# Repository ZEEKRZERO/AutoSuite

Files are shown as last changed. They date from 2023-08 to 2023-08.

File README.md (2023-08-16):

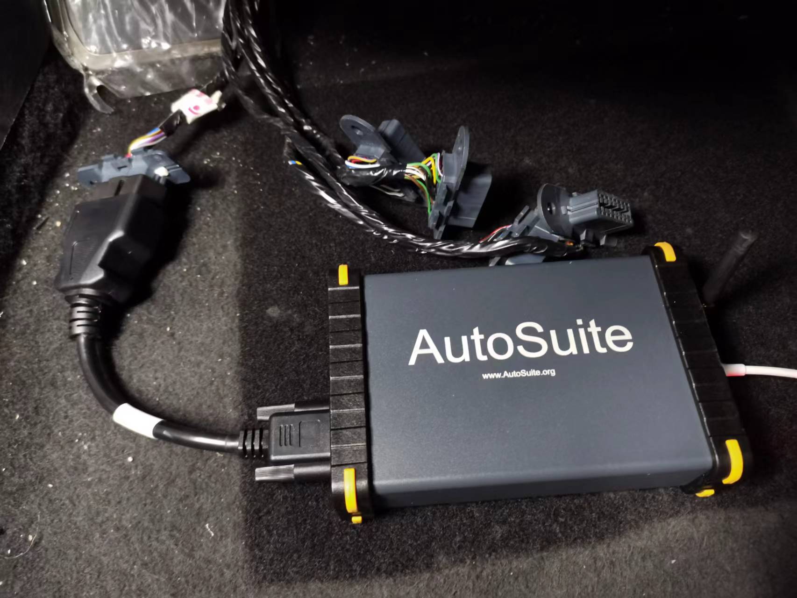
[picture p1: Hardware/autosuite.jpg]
harware

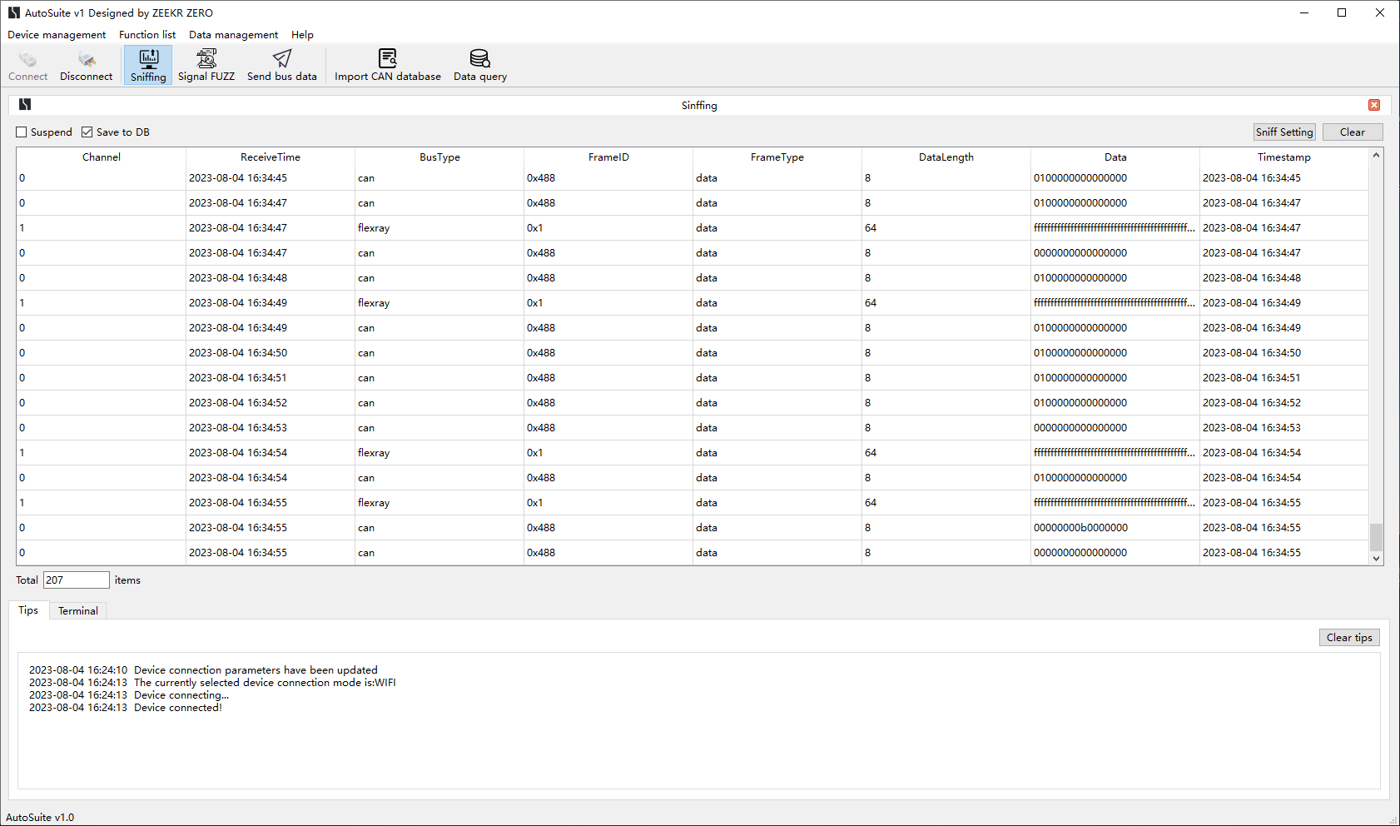
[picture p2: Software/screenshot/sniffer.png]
software1


# AutoSuite
Autosuite:an open source multi-protocol low-cost vehicle bus testing framework 
AutoSUite consisting of the hardware and software. AutoSuite can be used to access the FlexRay bus and simulate malicious ECUs to send forged data to realize cross-domain ECU attacks and discover potential security vulnerabilities.  
# Architecture
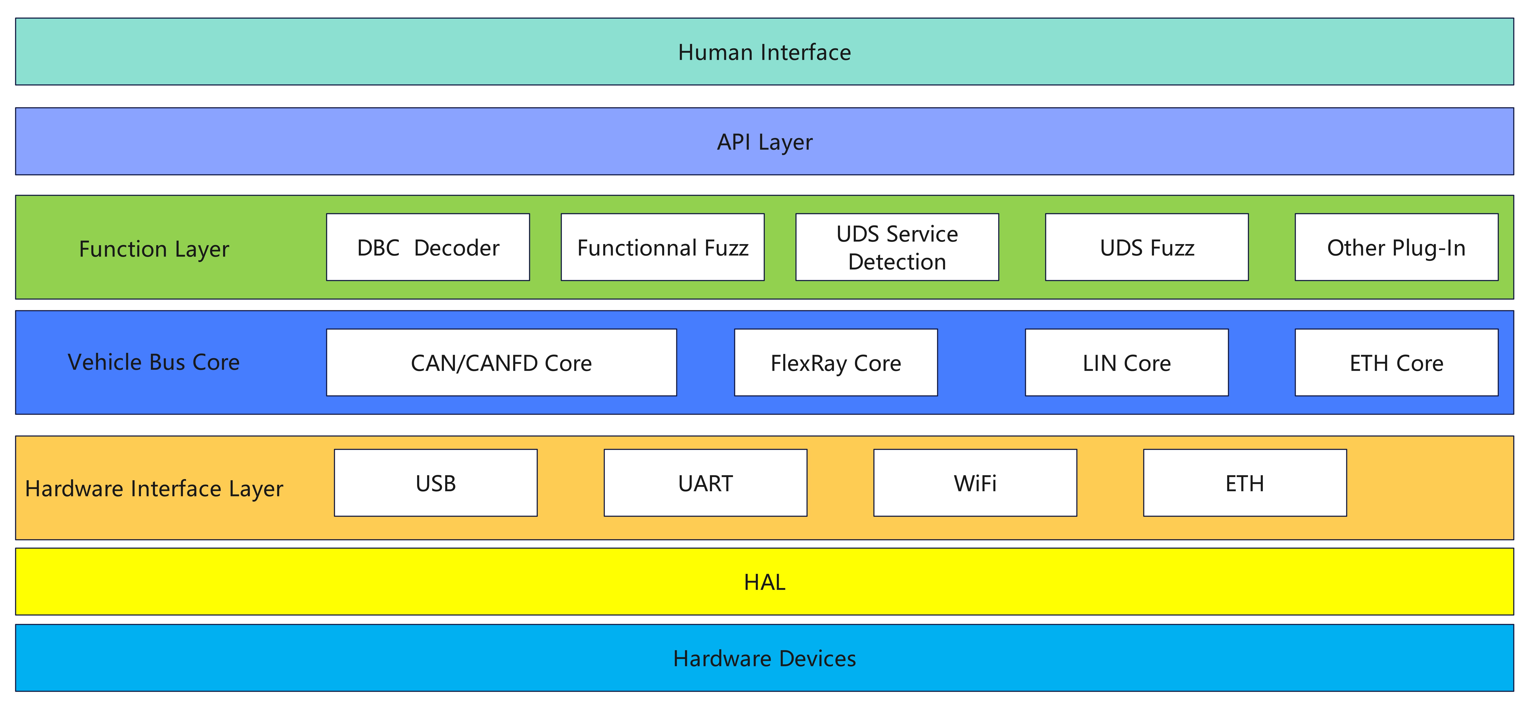
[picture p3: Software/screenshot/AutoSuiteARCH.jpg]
arch

## 3D
The STL/DXF/DWG file of metal shell of AutoSuite, you can 3D print or CNC your own AutoSuite shell.
## Hardware
Schematic and PCB included, you can make pcb with gerber file, component list is in BOM. 
## Firmware 
Including .elf file of MPC5748G and .bin file of ESP32(WiFi module).
## Software
### Requirements
```
pip install PySider6
pip install hidapi
pip install cantools
pip install pyserial
```
### Usage
```
cd AutoSuite/Software
python mainWindow.py
```
#### Connect Device
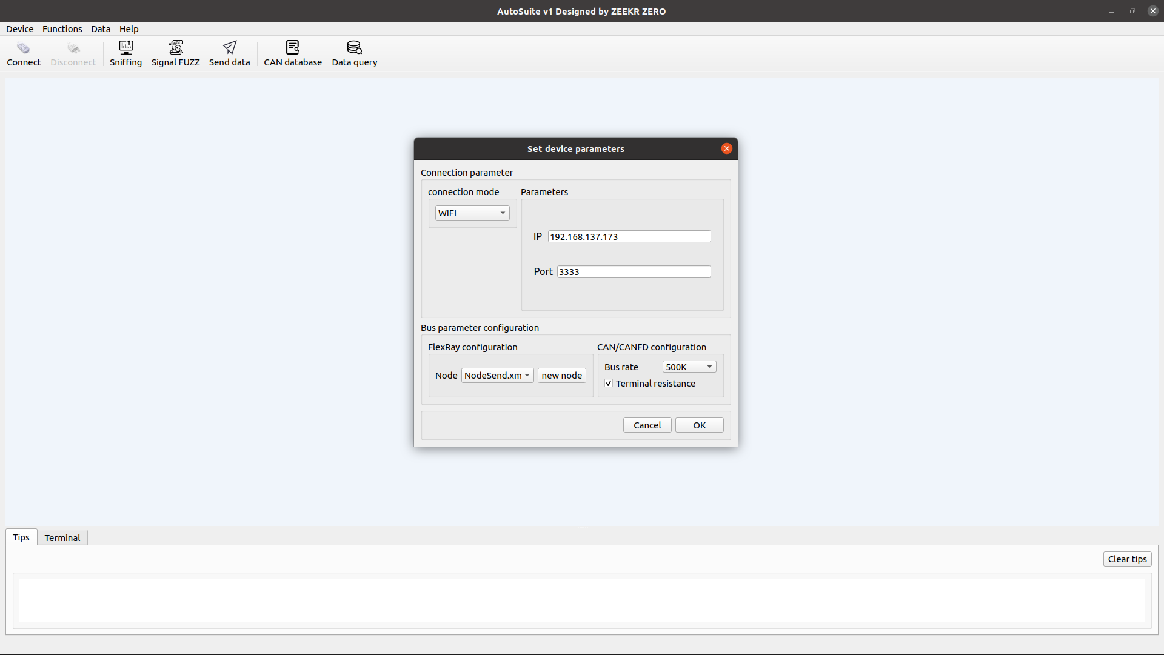
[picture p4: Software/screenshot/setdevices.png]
connect

* Click **Device-->Set Device Parameters**, choose **Connection Mode**, and config bus parameters.
* Click **Connect** to connect device. 

#### Sniffing 
sniff 
#### Signal Fuzz 
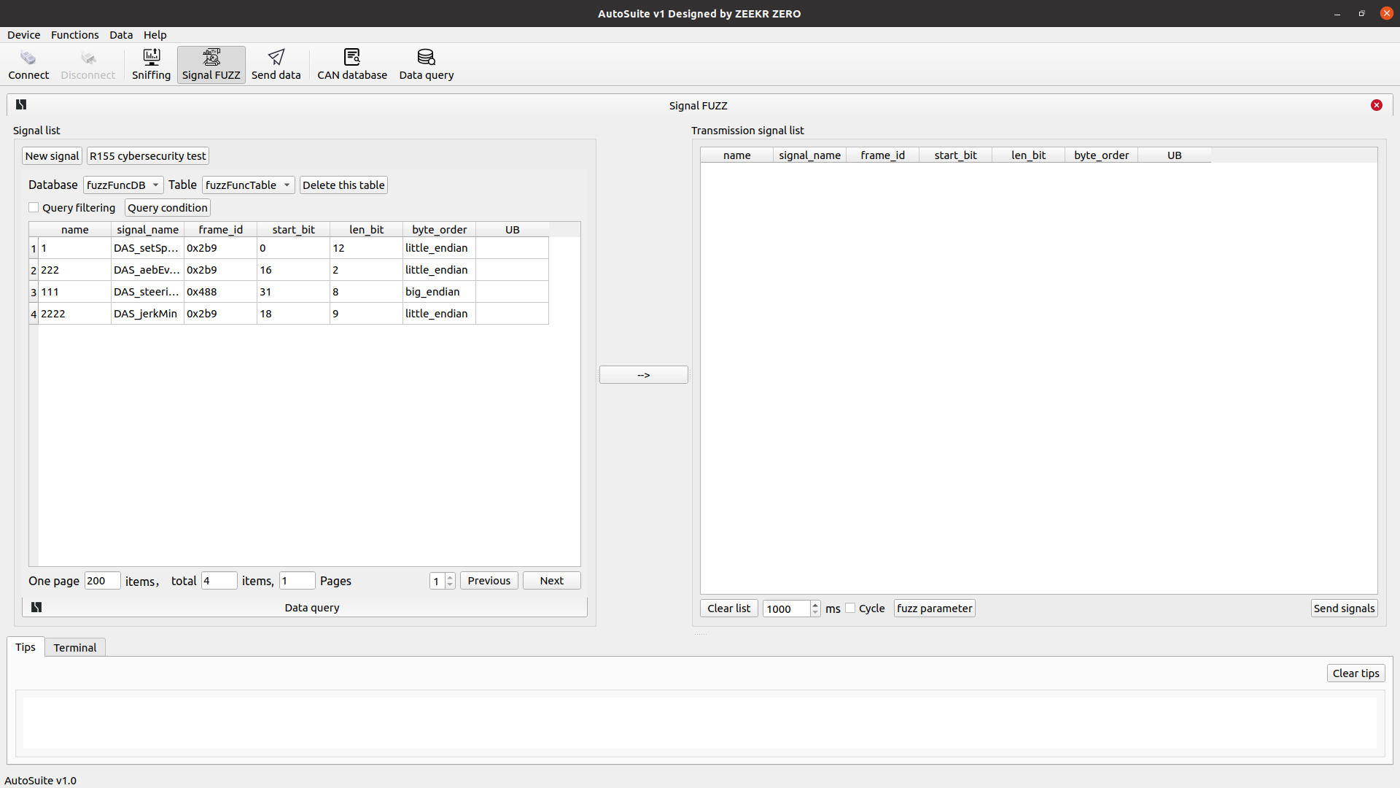
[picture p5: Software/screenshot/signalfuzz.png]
fuzz
 
#### Import and Parse DBC 
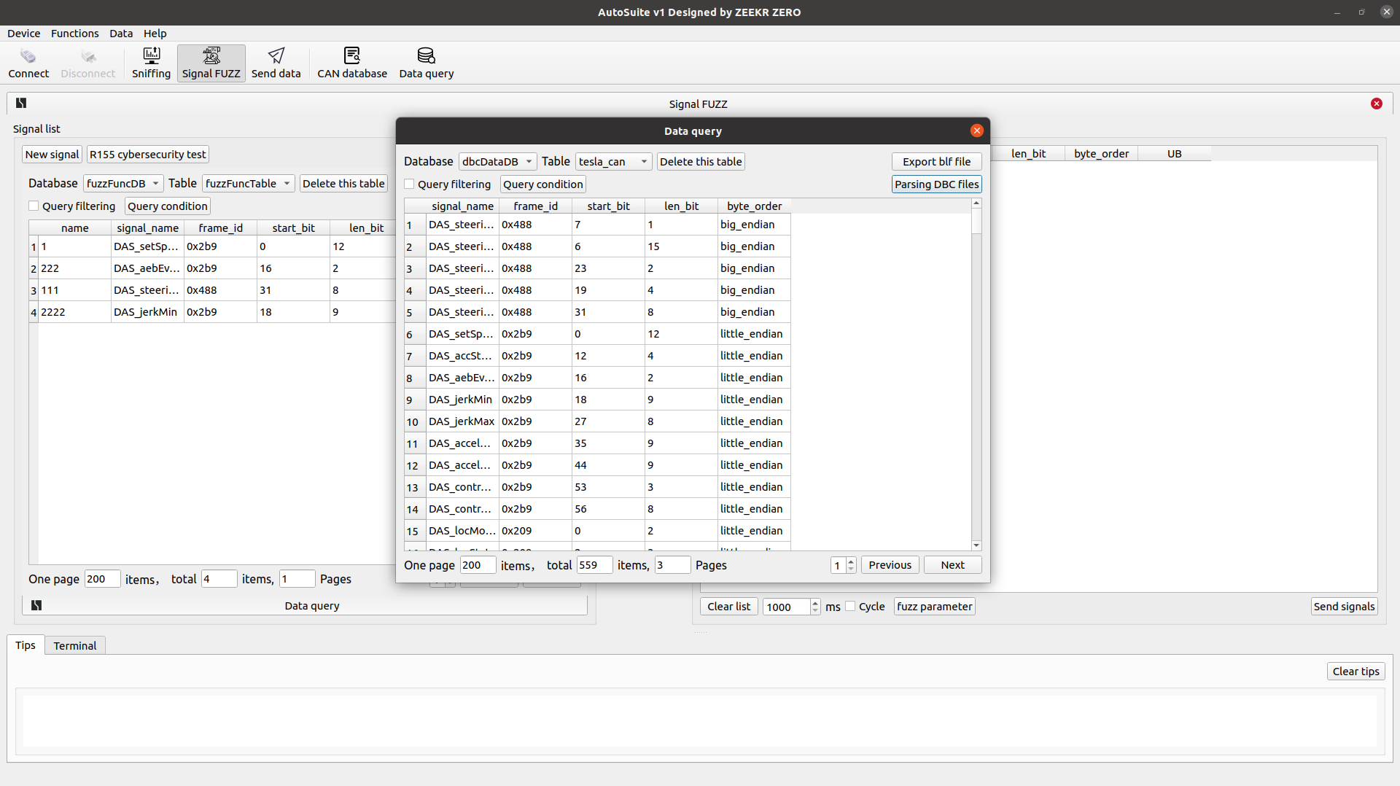
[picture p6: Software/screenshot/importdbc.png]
dbc
  
#### Send Data
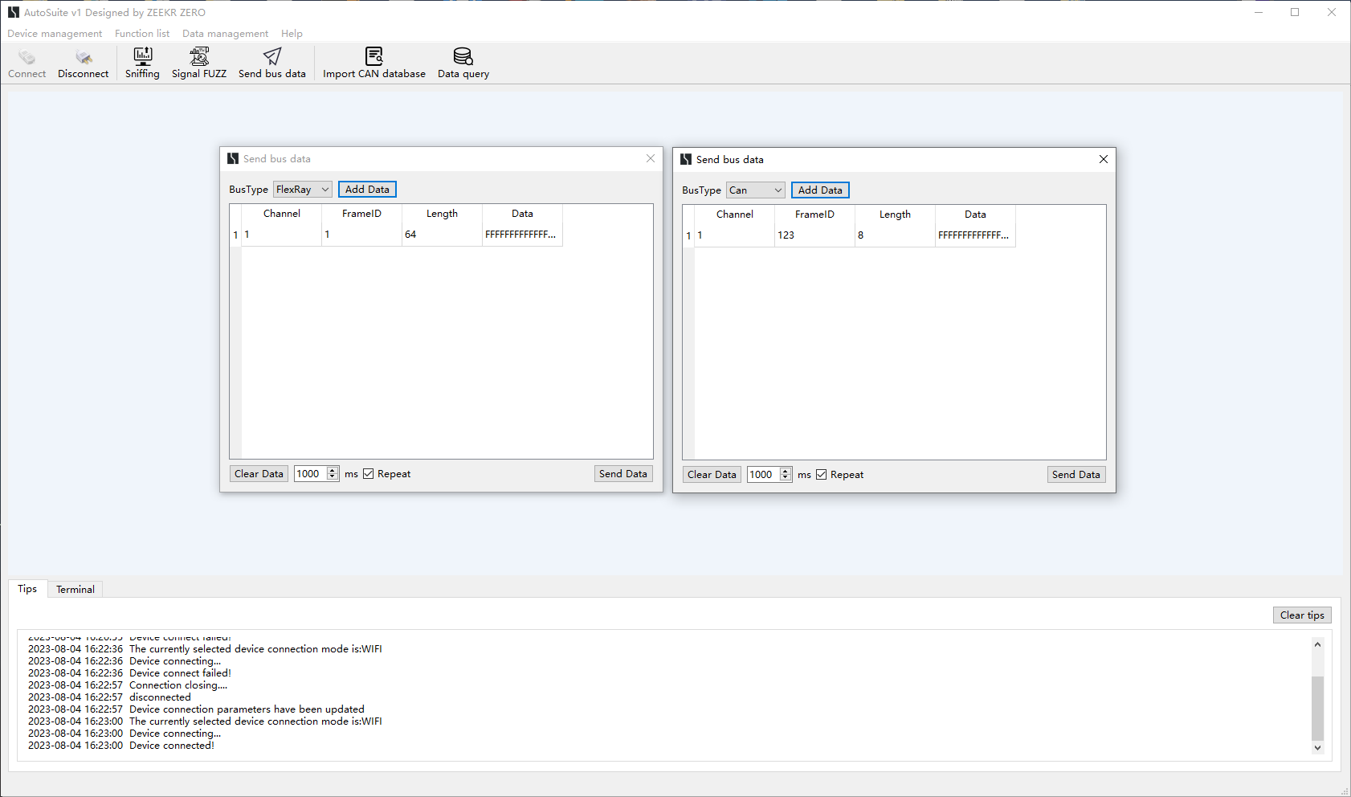
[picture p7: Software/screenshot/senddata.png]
senddata


### Create EXE
Run AutoSuite/Software/pack.bat
## Reference
* [MPC5748G Microcontroller Data Sheet](https://www.nxp.com.cn/docs/en/data-sheet/MPC5748G.pdf) 
* [MPC5748G Hardware Design Guidelines](https://www.nxp.com/webapp/Download?colCode=AN5220) 
* [MPC574xG SDK Hands On Training](https://www.nxp.com/webapp/Download?colCode=MPC574xG-SDK-HOT) 
* [openpilot/flexray_adapter/](https://github.com/nanamiwang/openpilot/tree/flexray_bounty/flexray_adapter) 
* [opendbc](https://github.com/commaai/opendbc) 
* [FlexRay Protocol Specification Version 2.1 Revision A](https://www.softwareresearch.net/fileadmin/src/docs/teaching/SS08/PS_VS/FlexRayCommunicationSystem.pdf)    
## Licensing
MIT License

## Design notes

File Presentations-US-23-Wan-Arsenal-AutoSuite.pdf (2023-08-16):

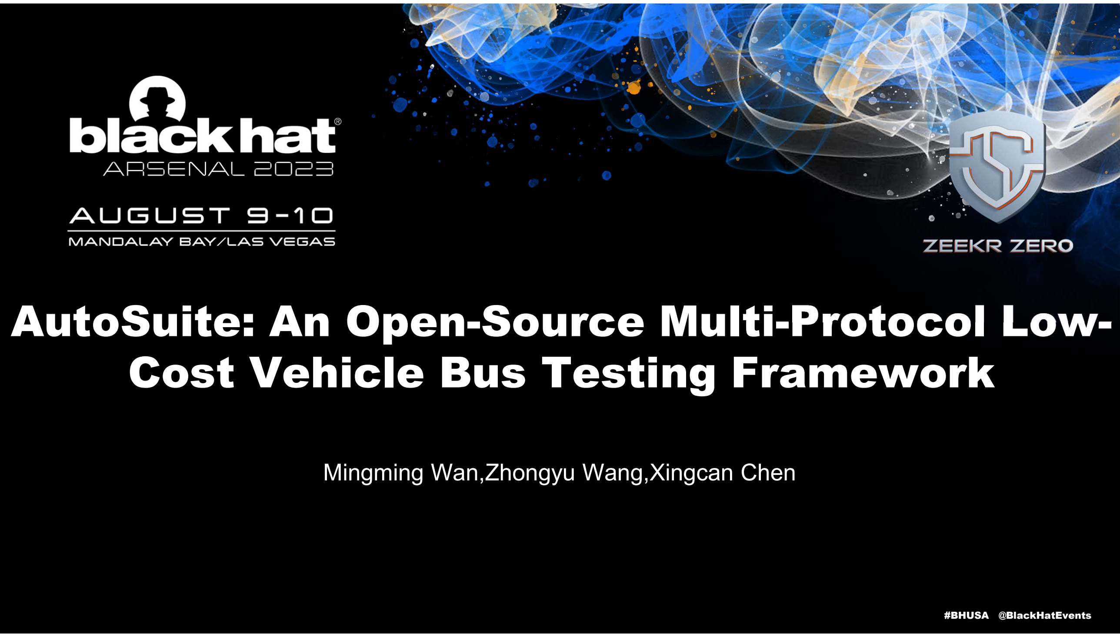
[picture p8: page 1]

## #BHUSA @BlackHatEvents

# AutoSuite: An Open-Source Multi-Protocol Low-Cost Vehicle Bus Testing Framework

# Mingming Wan,Zhongyu Wang,Xingcan Chen

## #BHUSA @BlackHatEvents

Information Classification: General

# Mingming Wan BlackHat USA 2017 Briefings Speaker Senior Hardware Engineer of ZEEKR AUTO

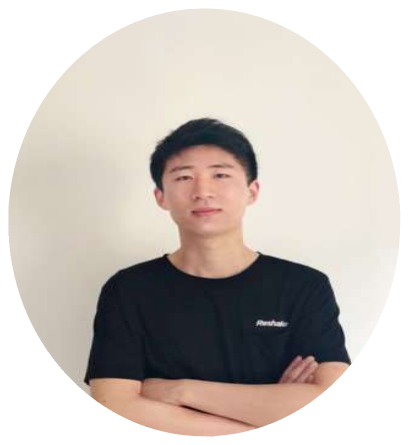
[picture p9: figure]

# wanmingming2008@gmail.com

# Zhongyu Wang IoT Group Head of ZEEKR AUTO wang3919379@gmail.com

# Xingcan Chen Hardware Security Engineer of ZEEKR AUTO icon.xxxc@gmail.com

# About US

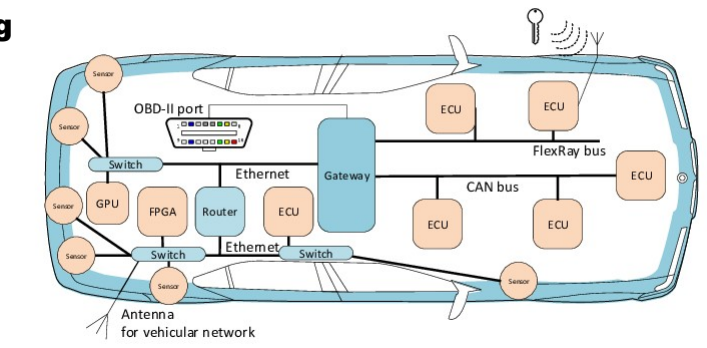
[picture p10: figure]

## #BHUSA @BlackHatEvents

Information Classification: General

# Vehicle Bus

# - Communication among different systems - Data Transfer in the form of signals

- FlexRay, CAN, LIN,

# ETH(DoIP) - Diagnostics for Troubleshooting

# Vehicle Bus Vulnerabilities

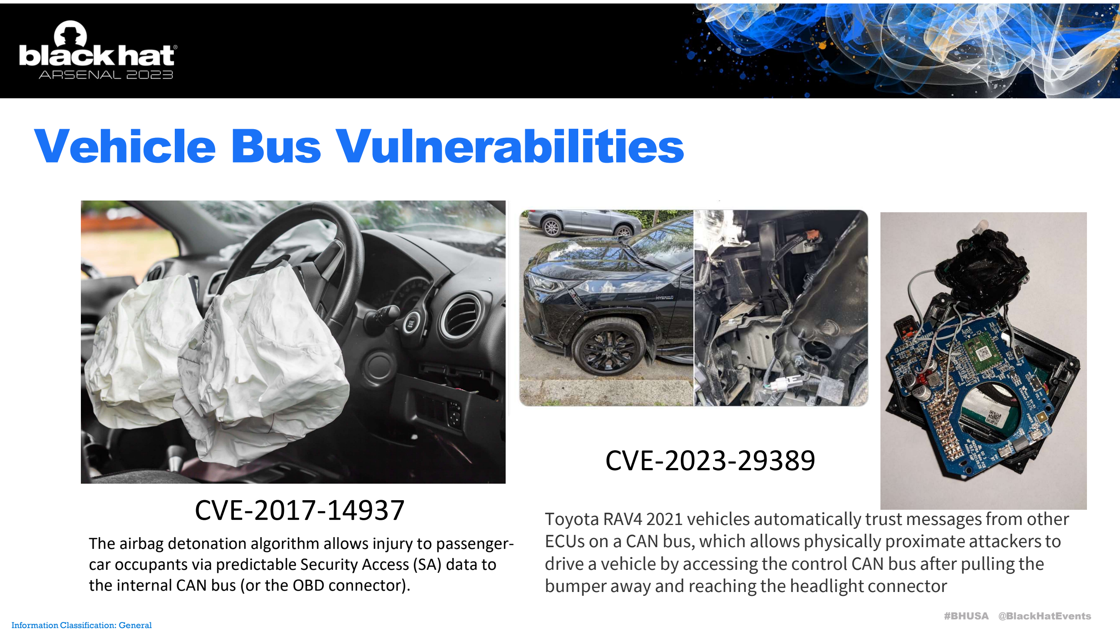
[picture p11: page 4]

## #BHUSA @BlackHatEvents

Information Classification: General

# CVE-2017-14937

# CVE-2023-29389

# The airbag detonation algorithm allows injury to passenger-car occupants via predictable Security Access (SA) data to

the internal CAN bus (or the OBD connector).

# Toyota RAV4 2021 vehicles automatically trust messages from other ECUs on a CAN bus, which allows physically proximate attackers to drive a vehicle by accessing the control CAN bus after pulling the bumper away and reaching the headlight connector

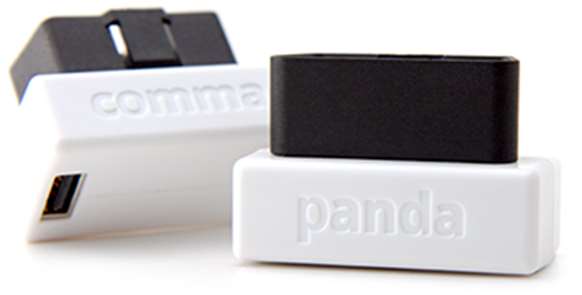
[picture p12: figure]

## #BHUSA @BlackHatEvents

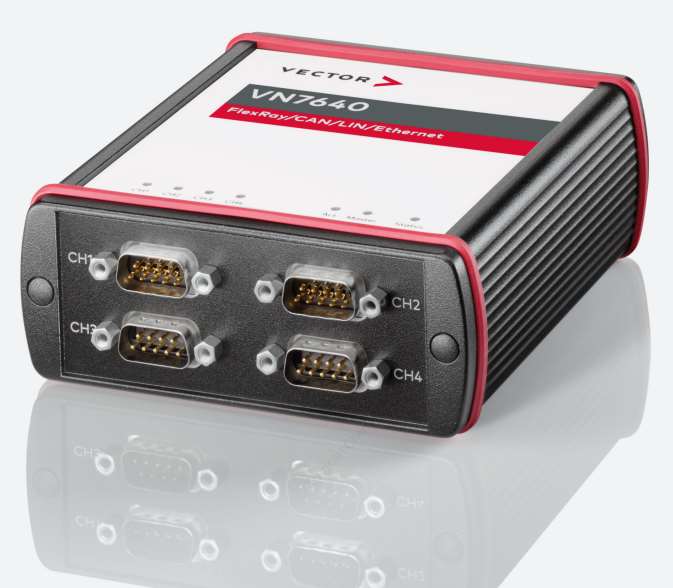
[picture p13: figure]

Information Classification: General

# Vehicle bus Tools

Vector VN7640 | CANable,CANdelight, | Panda
$50K | Open Source CAN ONLY

# FlexRay, CAN, LIN CAN,LIN

# OBD Port

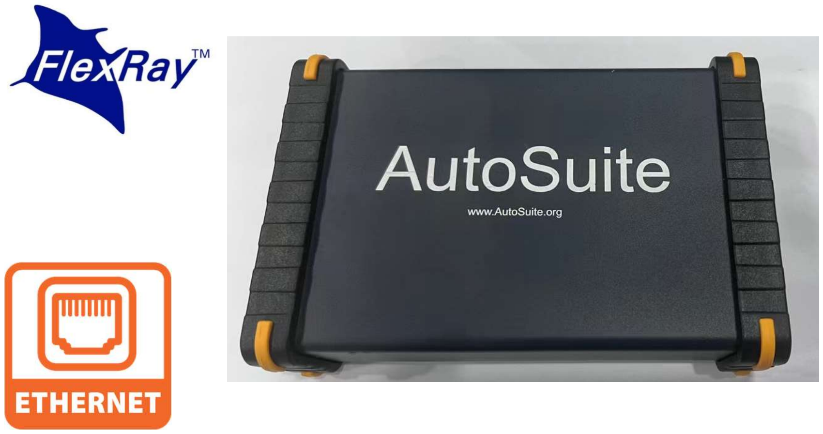
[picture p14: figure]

## #BHUSA @BlackHatEvents

Information Classification: General

# - Open-source

# - Multi-protocol supported

# - Low-cost

# - Functional Fuzz

# What is AutoSuite ?

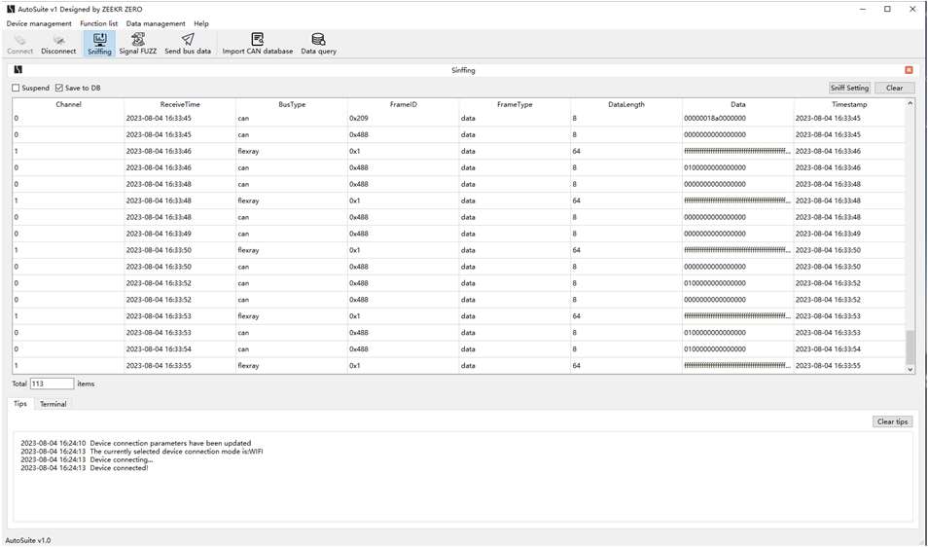
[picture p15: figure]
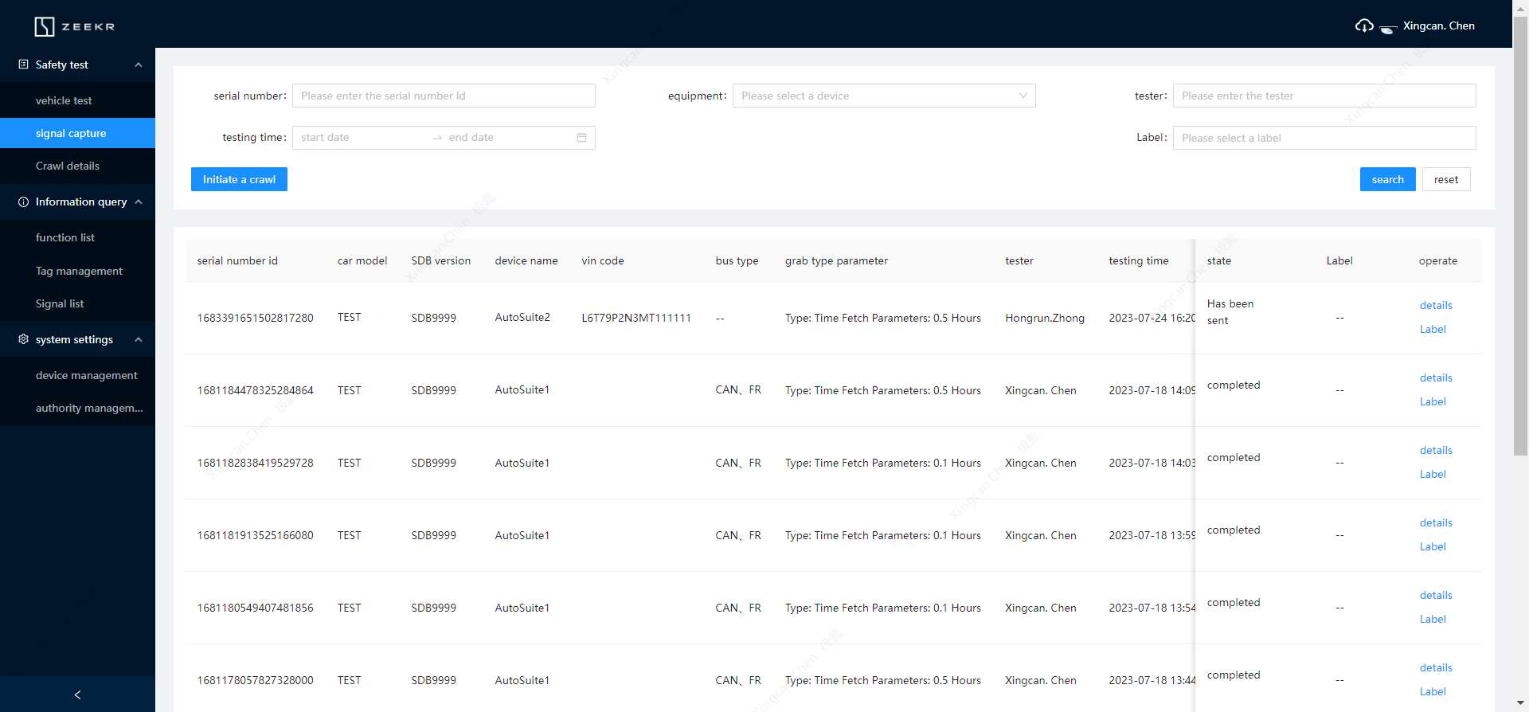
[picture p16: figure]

## #BHUSA @BlackHatEvents

Information Classification: General

# AutoSuite Features

# Plug-in Supported : Developed with PySider6

Cross-Platform: Windows, Linux,

# MAC

# Flexible application : Client and Website

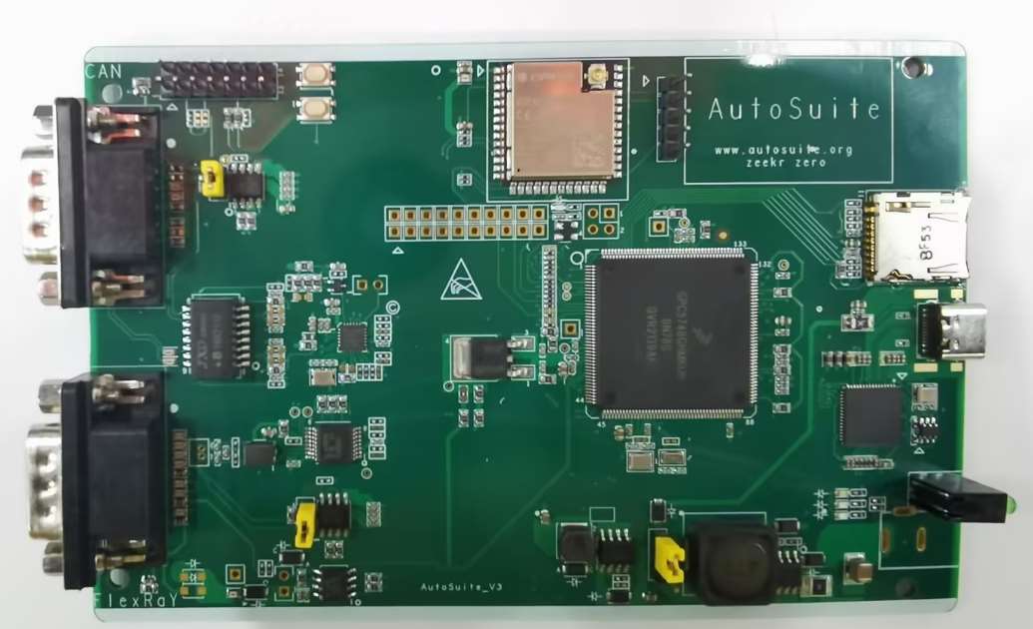
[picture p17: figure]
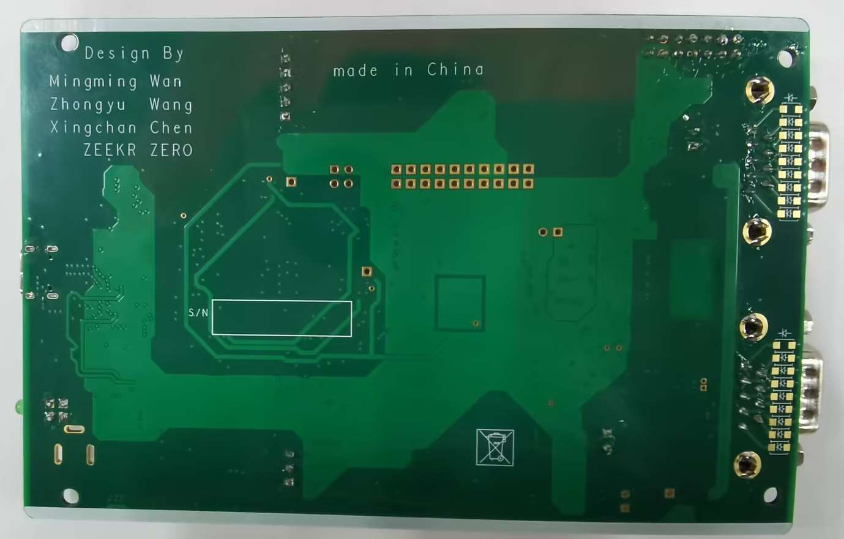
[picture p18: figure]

## #BHUSA @BlackHatEvents

Information Classification: General

# AutoSuiteFeatures

# 6-Layer PCB Both USB Type-C 5V and OBD power 12V options available WiFi Connect

# Coming soon：

# 5G module SD card storage 100BASE-T1

FlexRay CAN/CANFD LIN | ETH
Support √ √ √ | √
Current Channels 1 2 1 | 1
Max Channels 2 8 16 | 2

# AutoSuite

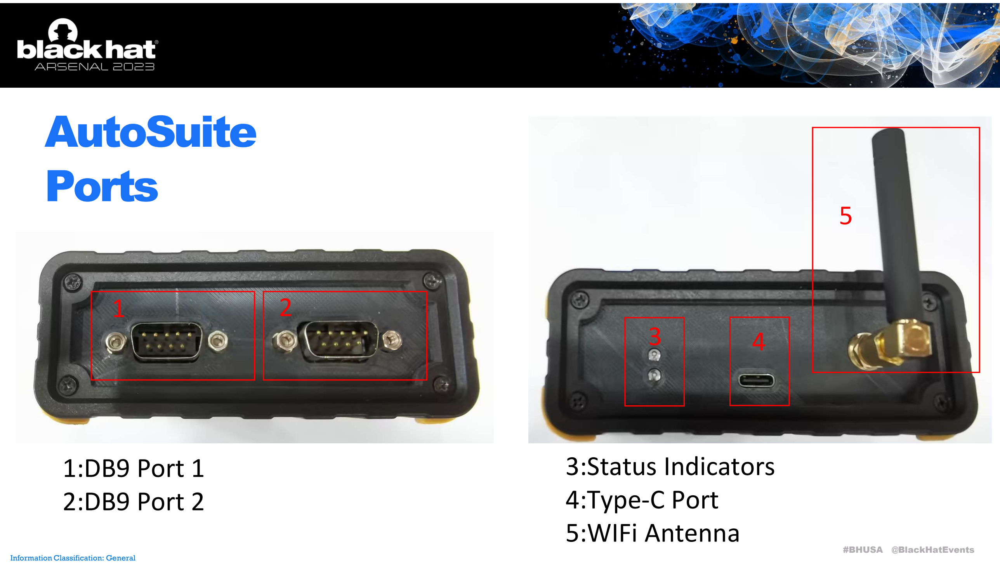
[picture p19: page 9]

## #BHUSA @BlackHatEvents

Information Classification: General

# Ports

1 2
3 4

5

# 1:DB9 Port 1 2:DB9 Port 2

# 3:Status Indicators 4:Type-C Port 5:WIFi Antenna

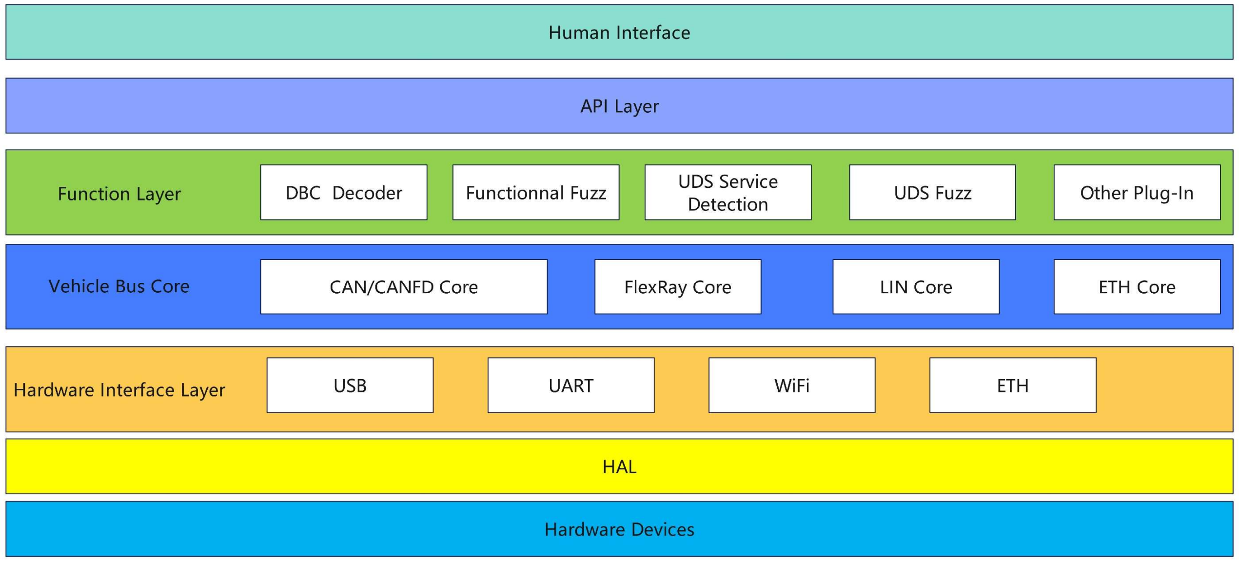
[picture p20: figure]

## #BHUSA @BlackHatEvents

Information Classification: General

# AutoSuite Architecture

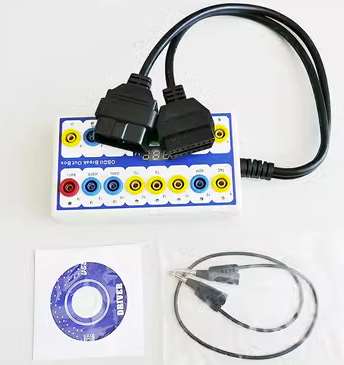
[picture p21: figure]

## #BHUSA @BlackHatEvents

Information Classification: General

# - There are lots of OBD ports for testing reserved

in vehicle R&D stage.

# - R&D engineer, functional safety testers and cyber security testers can directly and use

AutoBox for testing.

- Including FlexRay, CAN/CANFD, LIN and ETH.

# - If OBD port for testing is not reserved, broken

cable tool is helpful.

# How AutoSuite Work

# OBD(On-board diagnostics)

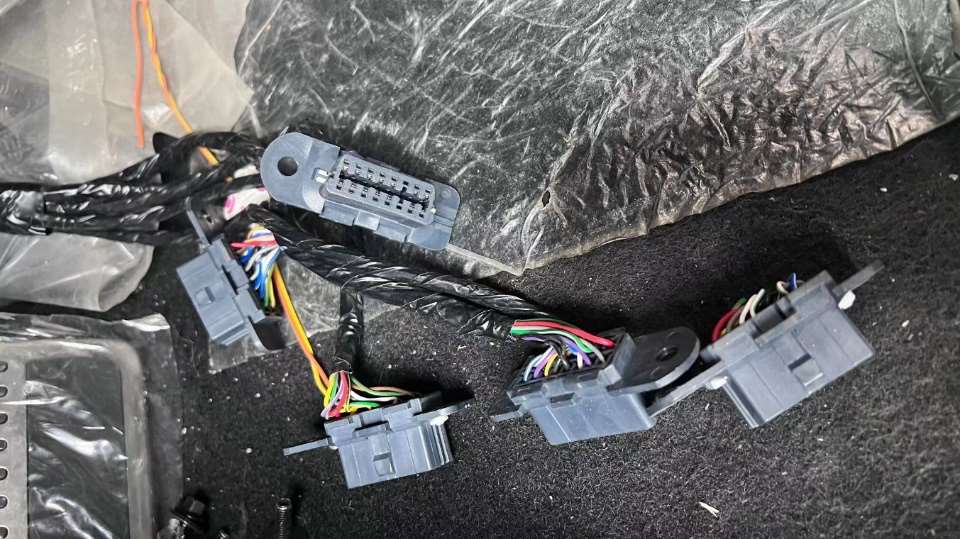
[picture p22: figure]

# OBD in Vehicle OBD converter

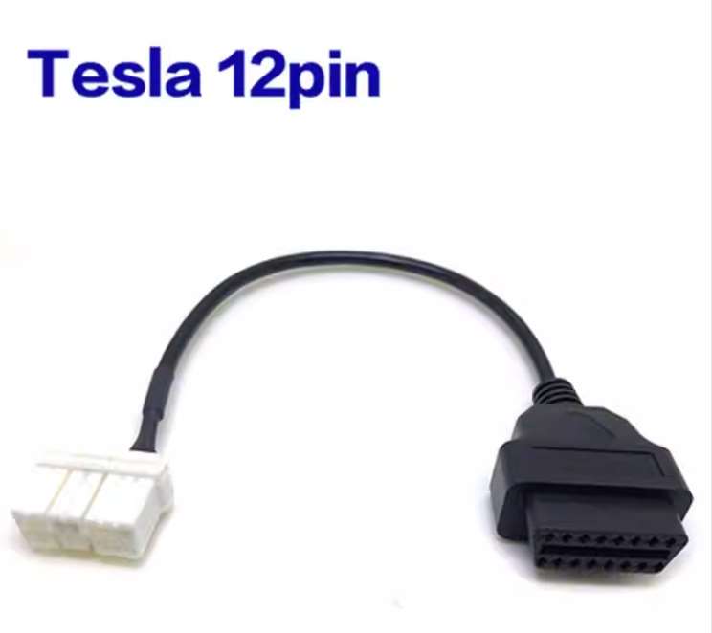
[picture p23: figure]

# OBD converter

# Broken cable tool

# AutoSuite Sniff

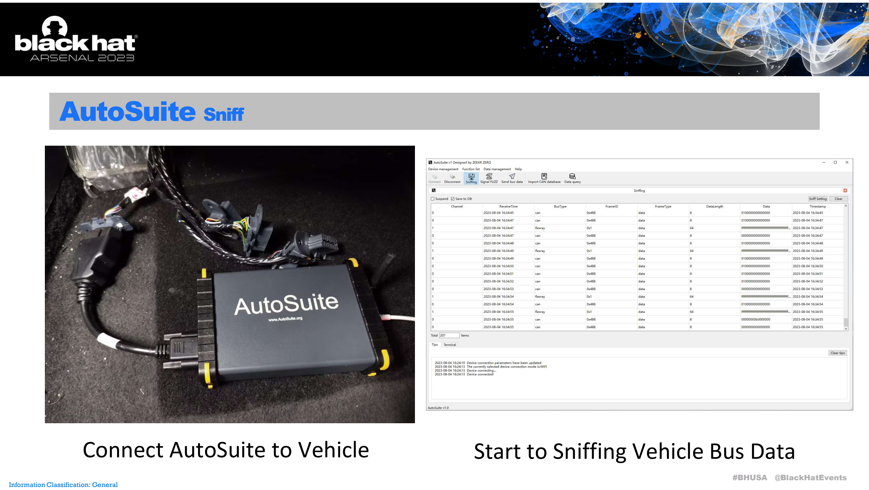
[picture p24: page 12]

## #BHUSA @BlackHatEvents

Information Classification: General

Connect AutoSuite to Vehicle | Start to Sniffing Vehicle Bus Data

## #BHUSA @BlackHatEvents

Information Classification: General

# Demo1 Vehicle Bus Sniffing

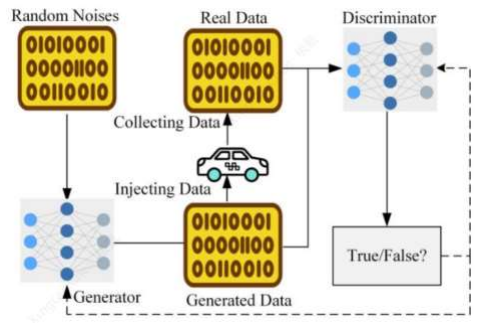
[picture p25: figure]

## #BHUSA @BlackHatEvents

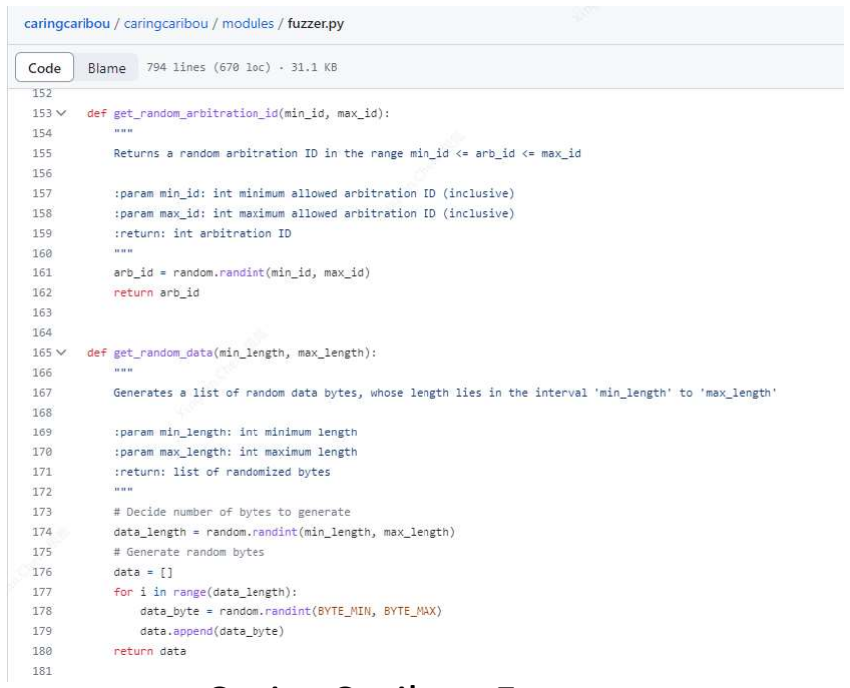
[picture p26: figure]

Information Classification: General

# AutoSuite Functional Fuzz

# CaringCaribou Fuzzer

# CAN-FT - Current Vehicle Fuzzing tools only focus on random generate frame ID or data frame

# - Hard to location root cause

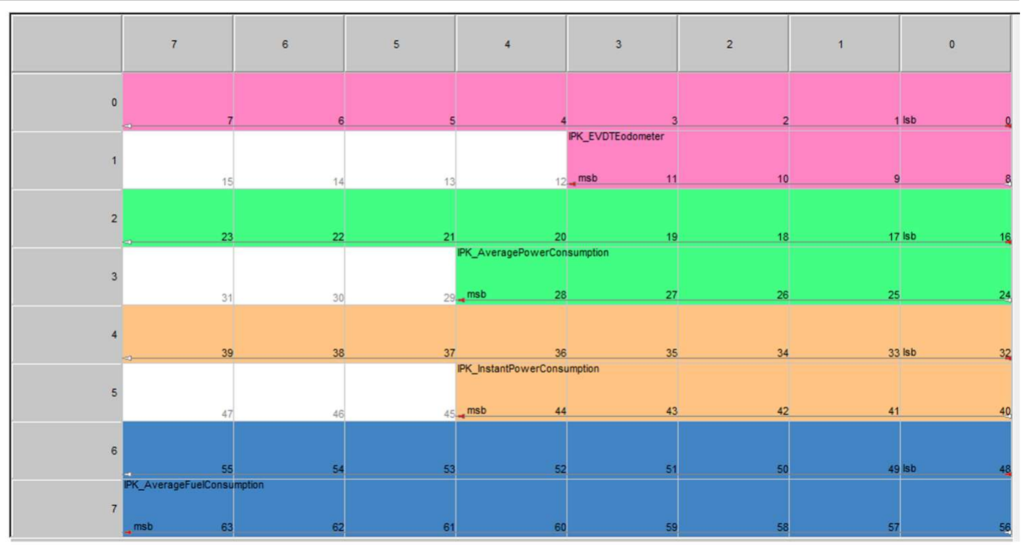
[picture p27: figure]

## #BHUSA @BlackHatEvents

Information Classification: General

# - Functional-level Fuzzing

# - DBC Decode

# - DTC Detection

# - UDS Fuzz

# Signal Layout in CAN Frame

# AutoSuite Functional Fuzz

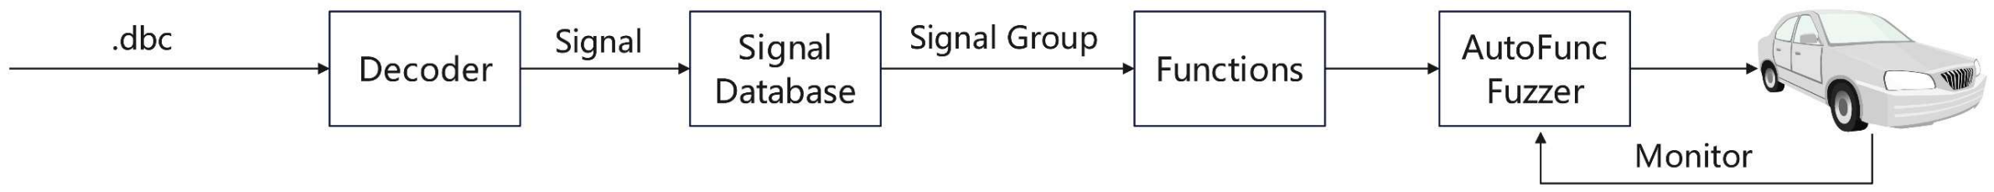
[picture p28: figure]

## #BHUSA @BlackHatEvents

Information Classification: General

# Workflow of Functional Fuzzer

# AutoSuite Functional Fuzz

# AutoSuite R155 Cybersecurity Test

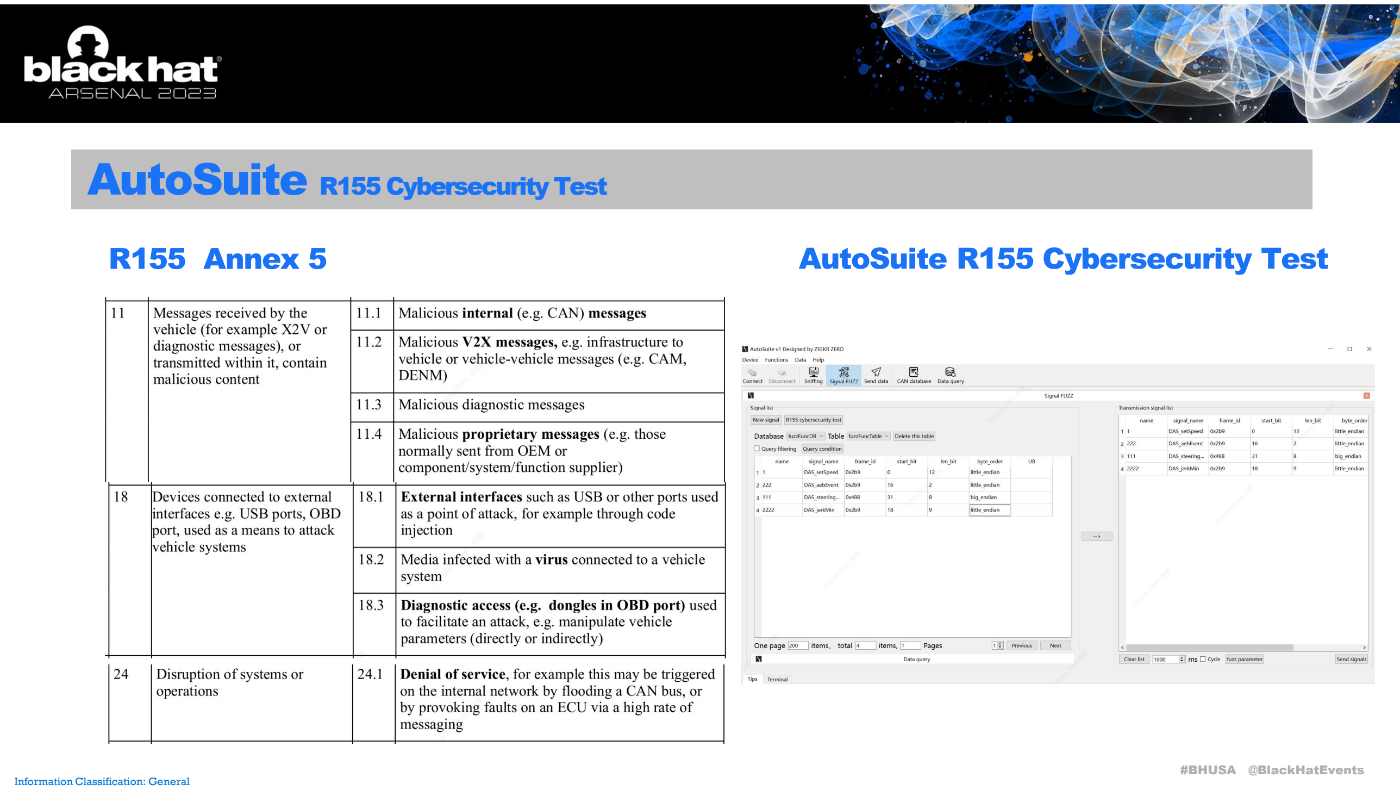
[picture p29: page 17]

## #BHUSA @BlackHatEvents

Information Classification: General

R155 Annex 5 | AutoSuite R155 Cybersecurity Test

## #BHUSA @BlackHatEvents

Information Classification: General

# Demo2 Functional Fuzz

## #BHUSA @BlackHatEvents

Information Classification: General

# Autosuite Application Scenarios

# - For WP.R155 Testing

# - For Chinese Vehicle security Law Testing

# - For Vehicle Charge Pile Testing

# Auto Cyber Security Testing

# - Personal vehicle security researcher

# Easy to use

# Low-Cost

# Personal Security Research

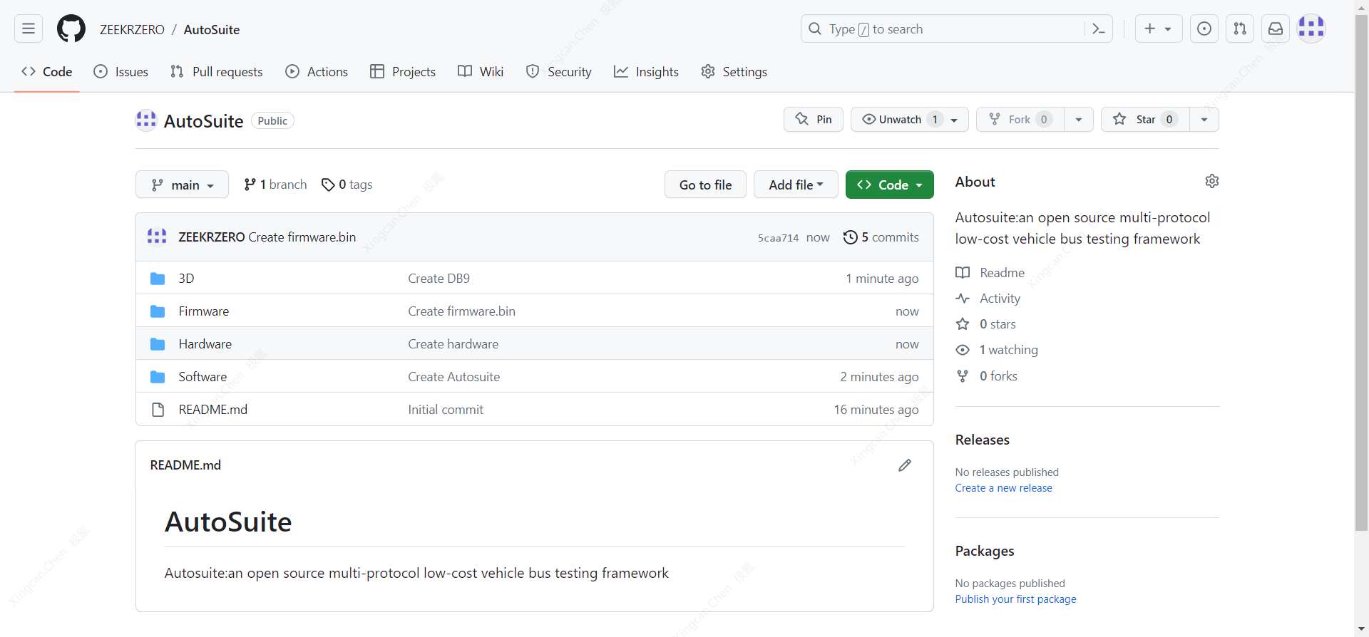
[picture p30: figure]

## #BHUSA @BlackHatEvents

Information Classification: General

# AutoSuite Opensource

# - GitHub.or www.Autosuite.org

# - AutoSuite software has uploaded

# - All PCB components can be purchased on Alibaba or DigiKey. You can make AutoSuite by

yourself in $200.

## #BHUSA @BlackHatEvents

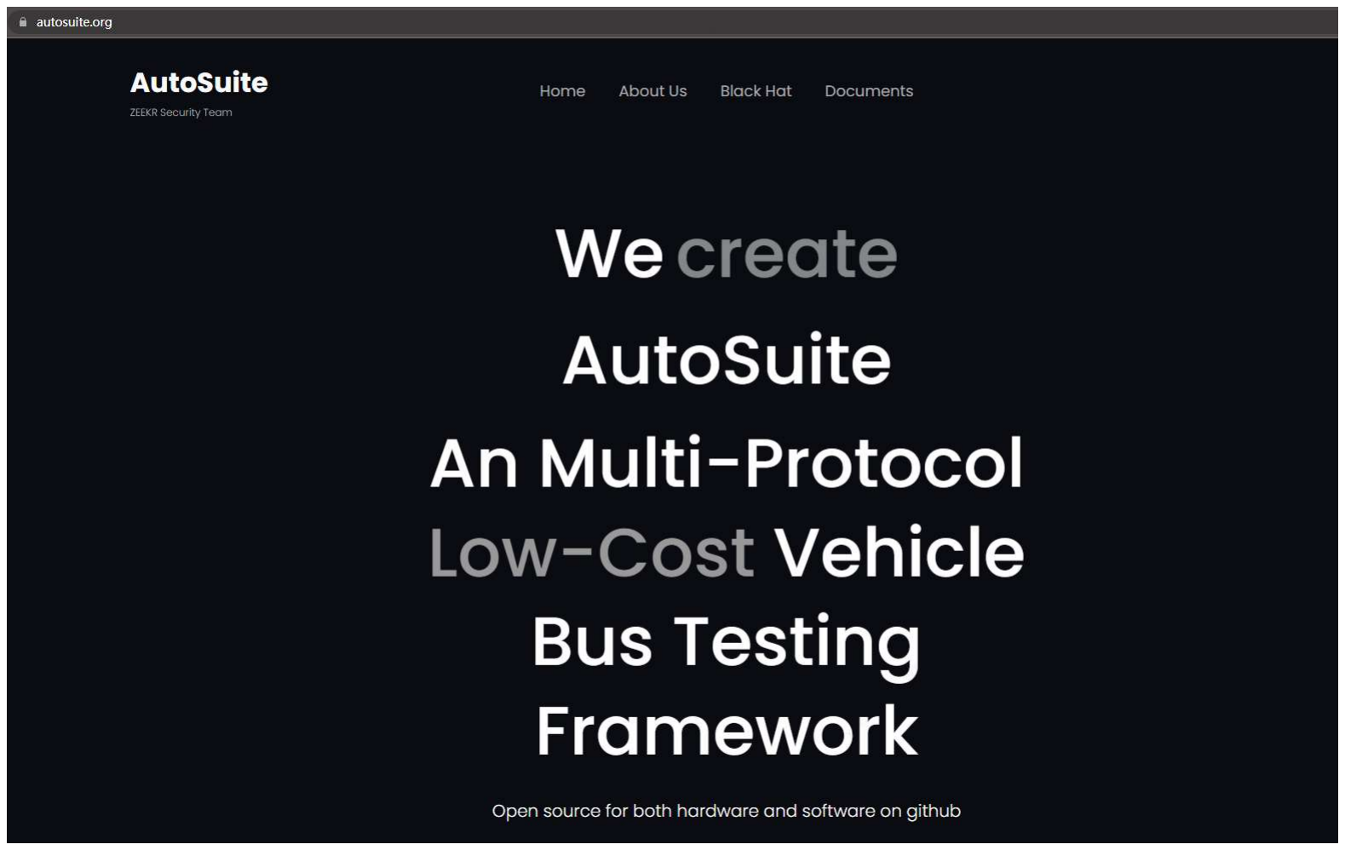
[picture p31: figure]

Information Classification: General

# TO DO

# - High-risk vulnerabilities, integrated POC (Proof of

Concept), modularization.

# - Additional hardware support for in-vehicle bus systems such as automotive Ethernet 100M/10M

and CANXL protocol.

# Please Access www.autosuite.org To Get Latest Information

## #BHUSA @BlackHatEvents

Information Classification: General

# Acknowledgments

# @Safe4 @Fengli Jiang @Alex Wang @Lakka @Jiantao Yan @Cawan

POC2022: Chen Nan & Chongyang Bao & Jiaming Tao, "Explore 'BUS' Mysteries via Automotive fuzzing'

## #BHUSA @BlackHatEvents

Information Classification: General

# Thank you

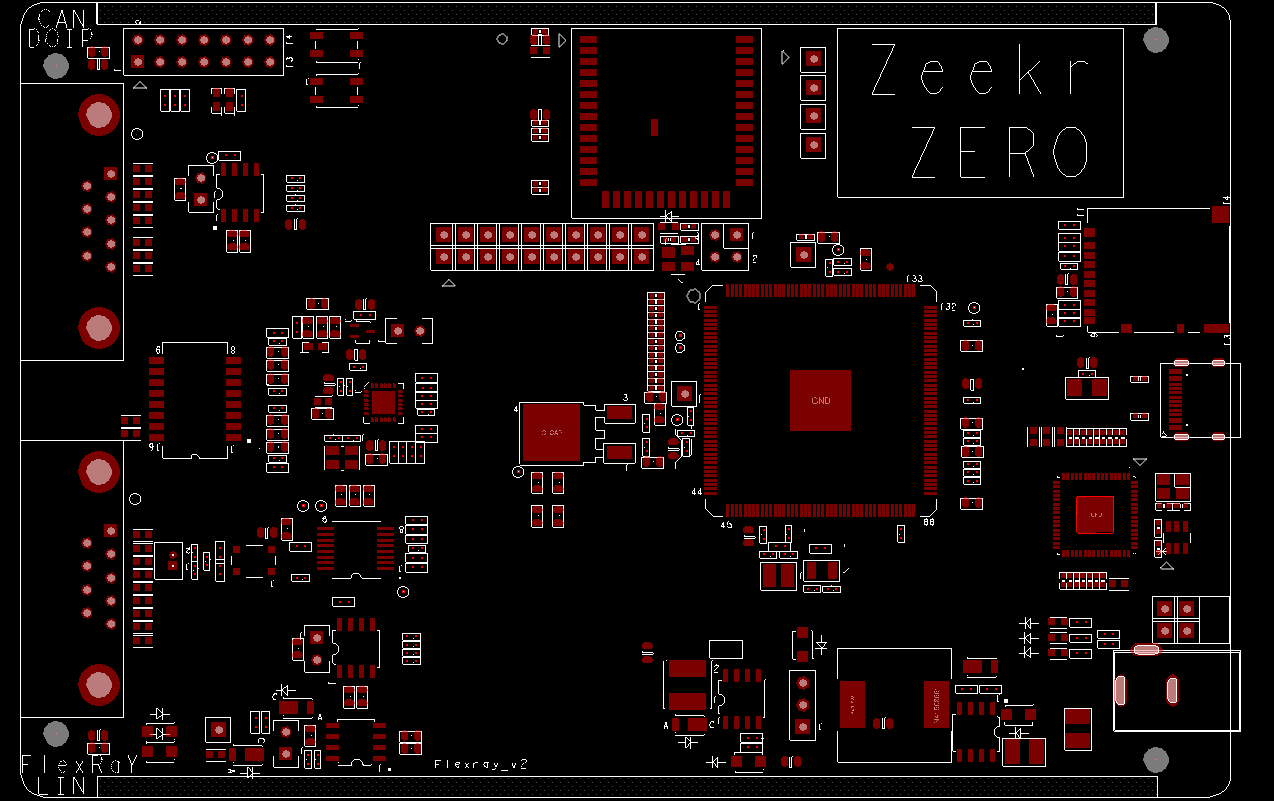
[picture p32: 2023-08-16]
Hardware/PCB/AutoSuite-TOP.png

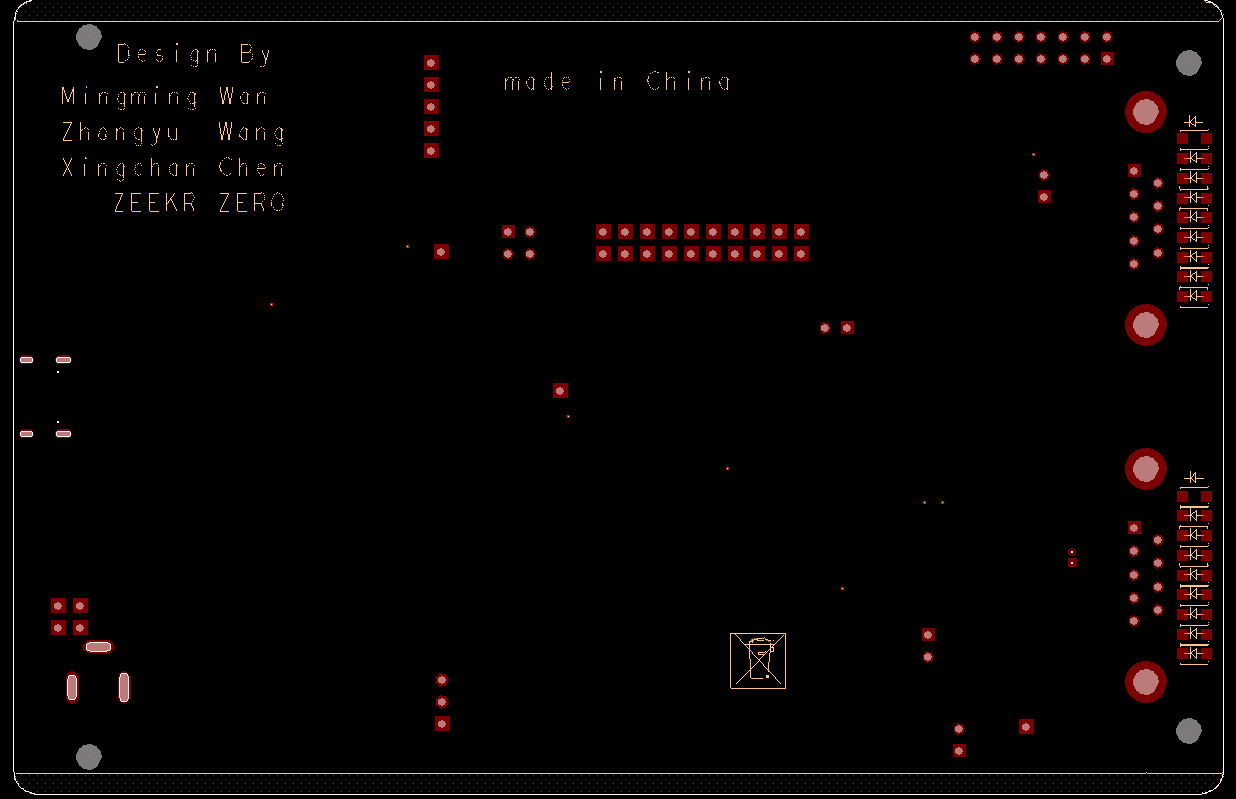
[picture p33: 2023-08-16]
Hardware/PCB/AutoSuite-Bottom.png

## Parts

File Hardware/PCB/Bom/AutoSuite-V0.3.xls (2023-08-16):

型号 | 封装 | 位号 | 元件编号
32.768KHZ | XTAL2-3P2X1P5-SM | Y4 | C130253
USB_TypeC_Receptacle_Mid-Mount | ylc_typec | J28 | C2982555
DLW43SH | IND_DLW43 | L3 | C123085
BAT54AWT1G | sot323_3p | D3 | C894269
4700pF | 0402 | C9,C60 | C1538
22uF | CC1210 | C71 | C52306
FT2232HQ | QFN64 | U499 | C193662
RB1-125BAG1A/TS21C_HF | xfmr16p_050_282x514 | J10 | C510548
TJA1044GT/3 | SO8_1P27_4X5 | U20,U21 | C961486
AP1509-SG-13 | SO8_1P27_4X5 | U18 | C151822
1.0UF | 0603 | C59 | C15849
22 | RC0603_OV | R151 | C23345
93LC56BT-I/OT | SOT-23-6_MC | U44 | C190271
SBR3U30P1 | powerdi-123_3mmx2mm | D1,D2,D5,D6 | C110517
12PF | 0402 | C79,C80,C81,C82 | C1547
40MHZ | xtal2_3p3x2p6 | Y5 | C255943
AP1509-33SG-13 | SO8_1P27_4X5 | U19 | C151823
2.2uF | 0402 | C26 | C12530
2.2uF | 0402 | C5,C48,C54,C69,C73,C1323,C1324,C1 | C12530
22uF | 0603 | C63,C66,C84 | C59461
2K2 | 0402 | R3424 | C25879
47 | 0402 | R23,R30 | C25118
47uH | ind2_12p8x12p8 | L8 | C2981394
4.7uF | 0402 | C222,C1000,C1200,C1777 | C23733
2.0K | 0402 | R1,R2 | C4109
600R/0.5A | 0603 | L53,L222,L333 | C1035
4.7uH | ind_5p2x5p2 | L7 | C135288
4.7UF | C0603 | C333 | C19666
4.7UF | 0603 | C52 | C19666
0R | 0402 | R1390,R1391,R1401,R1402,R1403,R1404,R129735,R129739,R129746,R129747,R138 | C17168
0R/NC | 0402 | R129727,R129728,R129729,R129730 | C17168
24PF | 0402 | C36,C39 | C285039
1.0UF | 0402 | C55,C58,C65,C67 | C52923
10uF | 0603 | C3,C20,C22,C27,C86,C1341,C1342 | C19702
SKRPABE010 | sw4_skrp | SW1,SW3 | C115360
KSZ8081RNACA | qfn24_4x4mm_slug | U17 | C100017
STM6315 | sot_143 | U7 | C2066710
12M | OSC-HCX-3SB | Y111 | C9002
27PF | 0402 | C7024,C8024 | C782161
5.1K | 0402 | R1340,R1341,R1384,R1392,R1394 | C25905
0.68UF | 0603 | C44,C62,C78 | C469639
PMEG4030ER | sod123w | D4,D8,D29 | C389355
0 | CC1210 | R1405 | C474103
0 | RC0603_OV | R3,R4,R15,R17,R42,R49,R58,R59,R60,R61,R62,R63,R67,R89,R91,R97,R98,R103,R111,R112,R113,R117,R124,R125,R126,R141,R142,R156,R1352,R1353,R1354,R1355,R1406,R50,R51 | C21189
6.49K | 0603 | R71 | C2933249
76.8R | 0402 | R165,R166 | C61601
4.7K | 0402 | R119,R1357 | C25900
1.5K | 0402 | R78,R79 | C25867
33 | 0402 | R77,R88,R94,R101,R102 | C25105
10.0K | 0402 | R73 | C25744
10K | 0402 | R19,R29,R35,R40,R54,R1344,R3324 | C25744
10K | 0402 | R28,R34,R36,R46,R47,R53,R87,R147,R148,R152,R153,R154,R155,R157 | C25744
2.2uF | 0603 | C1320,C1322 | C23630
270 | 0402 | R44 | C25099
270 | 0402 | R114,R132,R136 | C25099
10PF | 0402 | C8,C12 | C32949
1.0K | 0402 | R127 | C11702
560 | 0402 | R1349,R1350 | C25172
25MHz±10ppm12pF | SMD3225-4P | Y3 | C9006
520R | 0603 | R1395 | C23193
MJD31CT4G | to252_dpak | Q1 | C57942
0.1UF | 0402 | C4,C6,C10,C13,C14,C15,C28,C31,C40,C43,C45,C46,C50,C51,C56,C57,C61,C64,C68,C70,C74,C75,C76,C77,C85,C1325,C1326 | C1525
0.1UF | 0402 | C21 | C1525
100nF | 0402 | C1343 | C1525
0.1uF | 0402 | C555,C666,C999,C1100,C1555,C7888 | C1525
1000pF | 0402 | C34 | C1523
26OHM | IND_1206A | L4 | C2830251
120OHM | 0603 | L5 | C354394
LED_YELLOW | 0603 | DS2,DS9,DS10 | C965799
4A | 0603 | F5,F6,F7,F8,F9,F10,F11,F12,F13,F14,F15,F18,F19,F22,F23 | C210357
3.09kΩ±0.1% | 0402 | R122 | C852758
RED | 0603 | DS4 | C72041
120 | 0603 | R128,R1356 | C22787
ESP32-S3-WROOM-1U | SMD41_1P27_18 | U3 | C2980296
SPC5748GHK0AMKU6 | LQFP176_0P5_24X24_7P1EP | U16 | C2840606
0R-0603 | 603 | F17,F4,F16,F21,F3,F20 | C883088
1M | 0402 | R130,R133 | NC
1.69K | 0402 | R140 | NC
10K/NC | 0402 | R1345 | NC
0 | 0402 | R21 | NC
49.9 | 0603 | R75,R82,R104,R110 | NC
 | HDR2X2 | P1 | NC
HDR_1X1 | HDR101 | VSUP1,TPH1,VSUP2,TPH2,VSUP3,VSUP4,TPH4,VSUP5,TPH5,VSUP6,TPH6,VSUP7,TPH7,VSUP8,VSUP9,VSUP10,VSUP11,VSUP12,VSUP13,VSUP14,VSUP15,VSUP16,VSUP17,VSUP18,VSUP19,VSUP20,VSUP21,VSUP22,VSUP23,VSUP24,VSUP25 | NC
 | HDR_2X7 | P4 | NC
TJA1081B | SSOP16 | U10 | NC
TPAD_030 | TPAD_030 | TP16,TP17 | NC
DB9-RA | db_ra_plug-10 | J17,J31 | NC
MC33662BLEF | SO8_1P27_4X5 | U1 | NC
CON_1X2 | hdr102_1p25 | P2 | NC
PJ-002A | DC_PWR_JCK_9X14P4X11MMH | J30 | NC
HDR_1X3 | hdr1x3_2p54_th | J11 | NC
SD/MMCSKT | con_sdcard_std_14f_43_sm_ra | J15 | NC
型号 | 封装 | 位号 | NC
SBR3U30P1 | sod123w | D9,D10,D11,D12,D13,D14,D15,D17,D18,D19,D20,D21,D22,D23,D24,D25,D26,D27,D30,D31 | NC
TESTPOINT | tp_th_018 | TPV2,TPV4,TPV7,TPV8,TPV10,TPV12,TPV14,TPV15 | NC
NC | 0603 | R129749 | NC
50 | 0603 | R48 | NC
 | HDR1X2 | J5,J7,J16,J32 | NC
100PF | 0603 | 100PF,±5%,50V | NC

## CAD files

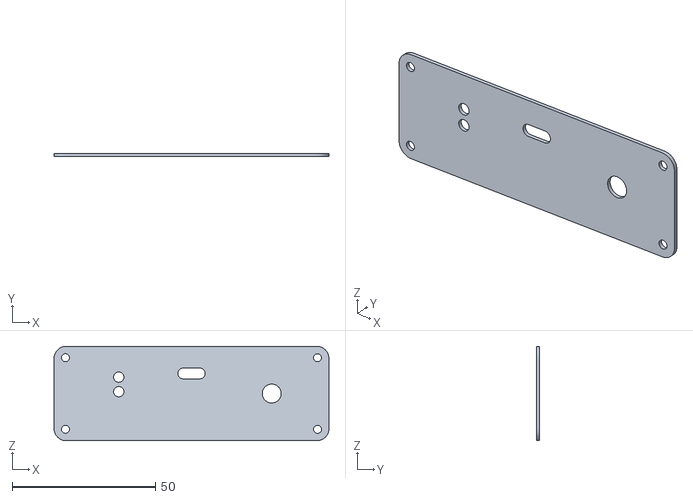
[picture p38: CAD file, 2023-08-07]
3D/typec.STL
96.0 x 1.12 x 33.0

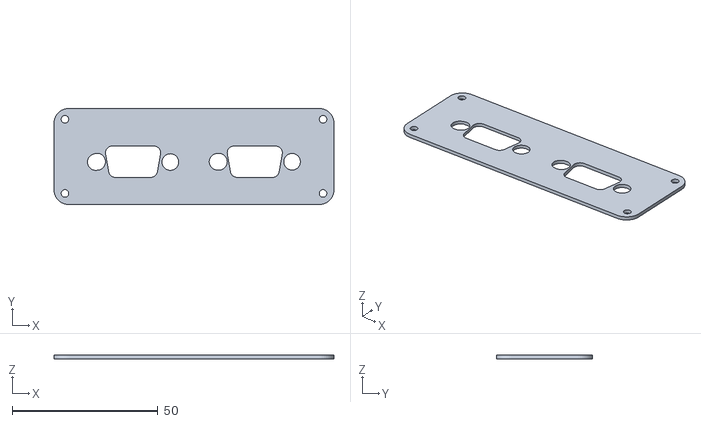
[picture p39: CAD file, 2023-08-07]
3D/DB9.STL
95.9 x 32.9 x 1.20

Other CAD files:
3D/metal shell .dwg
3D/DB9.DXF
3D/typec.DXF

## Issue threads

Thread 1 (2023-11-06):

smt贴片问题

mcblog, 2023-11-06:
硬件PCB开源方面有些疑问：理解贵团队硬件开源BOM文件时可能是按照当时的环境生成的半成品+后期自己加工，在我们进行PCB、SMT贴片工艺时以及跟PCB厂商多次沟通发现一些问题寻求帮助。
1、根据提供的BOM,发现在JLC smt贴片时有几样需要确认

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

不贴是否影响使用？
2、异常器件默认不贴是否影响使用？
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

3、是否会更新硬件部分内容，以达到任何人都可以直接通过提交相关文件给厂商 实现在默认配置下打板即可（不考虑元器件无货的情况）。或者是否有现成产品以便直接购买使用及测试？

wanming2008, 2023-11-16:
1:MC3662，tja1081不贴肯定影响使用，这2个是接口芯片。不贴会影响总线功能。每个贴片厂的贴贴片不同，需要您自己和贴片厂沟通适配。这个芯片一般贴片厂都买不到。需要您淘宝或者digikey购买后寄给贴片厂
spc5748是主芯片，不贴肯定影响使用，你这个错误和bom无关，是贴片厂没有元器件导致的。同样需要自行购买后寄给贴片厂，其他带有nc字样或者一些jp插头都是测试点的都可以不贴片。并不会影响功能的使用。核心是那2个DB9的接头需要连接。
2：D30和D31如果您使用usb C口供电是不需要贴片的。
如果使用OBD供电的话，看使用哪一个obd，如果是J17这个OBD的12V供电就需要贴片D30
如果是使用J31这个obd供电就需要贴片D31，我们是默认贴片的因为我们的应用和您的不一定相同。
如果用usb供电这2个都不贴。这里是非常重要的，因为如果贴错可能上电就烧毁了
3：我们会本周更新一个bom的精简版本，删除可以不贴的元器件，以防止误贴片。这样根据精简版本的bom贴片就一定不会贴错。就算少贴了也不会造成贴出来的芯片短路或者烧毁的情况。至于您提到的文件直接交给厂商就可以打板子的问题，首先PCB肯定是可以直接打板的。贴片的话，每个人的贴片厂不同，包括我们自己也没有做到一次贴片成功。除非批量化300片，1000片这种小批量贴片工厂才会配合我们。所以我们还是建议贴片时候和贴片厂一起核对问题，然后针对具体的问题，来讨论细节。
比如D30和D31的贴片。您提出了这个问题，我们就可以及时沟通，
但我bom中无论写贴还是不贴都可能给obd供电的测试人员带来误导，产生烧毁pcb板子的情况。特别是主芯片mpc5748价格昂贵。
4：目前我们没有量产autosuite的计划。
但是您贴片时候有任何的具体的具体问题都可以在这里提问。比如D30这种。
autosuite确实只是一个简单的工具。还未到直接量产的能力，软件也有很多功能没有开发完成。后续更新需要我们投入更多的人力和物力，但是目前我们没有太多的时间全职支持autosuite的开发功能。所以目前状态下确实需要使用者有一些技术功底。
最后感谢您的建议。

1: MC3662 and tja1081 will definitely affect their use if not pasted. These two are interface chips. Not pasting will affect the bus function. Each patch factory has different patches, and you need to communicate and adapt with the patch factory yourself. This chip is generally not available to SMT factories. We need you to purchase from Taobao or Digikey and send it to the SMT factory

SPc5748 is the main chip, and not sticking it will definitely affect its use. Your error is not related to BOM, but is caused by the lack of components in the chip factory. You also need to purchase it yourself and send it to the SMT factory. Other products with the words "nc" or some JP plugs that are test points can be SMT free. It will not affect the use of the function. The core is that the two DB9 connectors need to be connected.

2: D30 and D31 do not require a patch if you use a USB C port for power supply.

If using OBD power supply, it depends on which OBD is used. If it is the 12V power supply of the J17 OBD, a D30 patch is required

If using J31 for OBD power supply, we need to mount D31. We default to mounting because our application may not be the same as yours.

If using USB power supply, neither of these two will be connected. This is very important because if it is pasted incorrectly, it may burn out when powered on

3: We will update a streamlined version of BOM this week, removing components that can be left unused to prevent incorrect placement. This way, based on the simplified version of the BOM patch, it will definitely not be pasted incorrectly. Even if it is not pasted, it will not cause a short circuit or burning of the pasted chip. As for the issue of directly submitting the documents you mentioned to the manufacturer to be printed, PCB can definitely be printed directly. When it comes to patches, everyone's patch factory is different, and we ourselves have not achieved a single successful patch. Unless we mass produce 300 pieces or 1000 pieces, small batch SMT factories will cooperate with us. So we still suggest checking the issue with the SMT factory during the placement process, and then discussing the details based on the specific issue.

For example, the patches for D30 and D31. If you raise this issue, we can communicate in a timely manner,

But whether I write or do not paste in my BOM, it may mislead the testing personnel of OBD power supply, resulting in the situation of burning the PCB board. Especially the main chip MPC5748 is expensive.

4: At present, we have no plans to mass produce autosuite.

But if you have any specific questions when pasting, you can ask them here. For example, D30.

Thank you for your suggestion.

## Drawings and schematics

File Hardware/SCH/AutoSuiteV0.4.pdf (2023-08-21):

## CAN termination resistor footprint. Place on

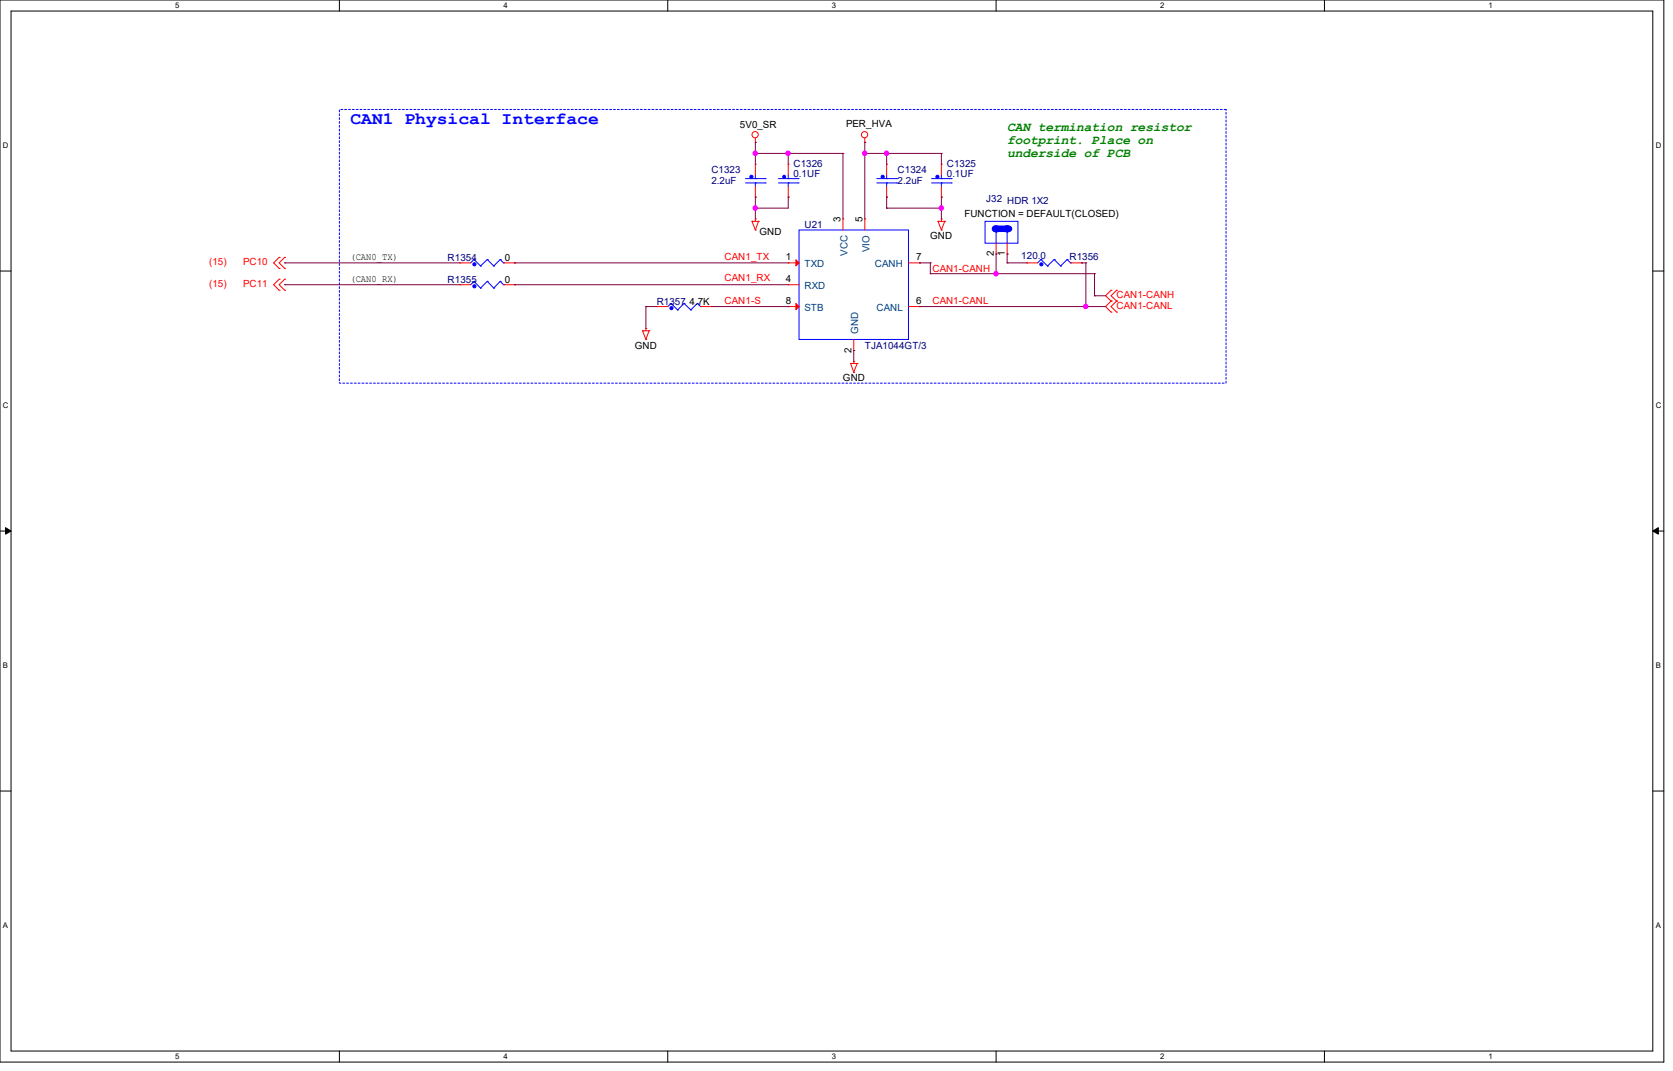
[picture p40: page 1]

J32 HDR 1X2 FUNCTION = DEFAULT(CLOSED) 2

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
# Comms 1 - CAN and LIN

# Revision Information

Rev | Date | Designer | Comments

# Power - MCU Power

# Reset and JTAG

# Sheet 8 Sheet 9 Sheet 10 Sheet 11 Sheet 12 Sheet 13 Sheet 14 Sheet 15

# Sheet 2 Sheet 3 Sheet 4 Sheet 5 Sheet 6

MCU GPIO 1 | Sheet 7

# Comms 4 - Ethernet (RMII Mode)

# Comms 3 - USB Host Interface (device footprints only)

# Comms 2 - OpenSDA

# MCU GPIO 2

# Comms 5 - FlexRay User - Switches, LED's ,Potentiometer and SD CARD User - GPIO Connectors

# Table Of Contents:

# FlexRay V1 2023.02.13

# Power - Main input, 5V and 3.3V regulator

# Clocks

# Power - MCU Decoupling

A1 | 13 Jan 2023 | Mingming Wan
Drawing Title: Size | Document Number | Rev Date: | Sheet | of Page Title:

Designer:

Drawn by:

Approved:

## Automotive Product Group

6501 William Cannon Drive West Austin, TX 78735-8598 This document contains information proprietary to NXP and shall not be used for engineering design,

procurement or manufacture in whole or in part without the express written permission of NXP Semiconductors.

ICAP Classification: | CP: | IUO: | PUBI: SCH-29030 | PDF: SPF-29030 | D1 DEVKIT-MPC5748G

B Monday, April 03, 2023

Index and Title Page C Neacsu Pesses Philip C Neacsu

1 | 15 X Drawing Title: Size | Document Number | Rev Date: | Sheet | of Page Title:
Designer:

Drawn by:

Approved:

## Automotive Product Group

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

procurement or manufacture in whole or in part without the express written permission of NXP Semiconductors.

ICAP Classification: | CP: | IUO: | PUBI: SCH-29030 | PDF: SPF-29030 | D1 DEVKIT-MPC5748G

B Monday, April 03, 2023

Index and Title Page C Neacsu Pesses Philip C Neacsu

1 | 15 X Drawing Title: Size | Document Number | Rev Date: | Sheet | of Page Title:
Designer:

Drawn by:

Approved:

## Automotive Product Group

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

procurement or manufacture in whole or in part without the express written permission of NXP Semiconductors.

ICAP Classification: | CP: | IUO: | PUBI: SCH-29030 | PDF: SPF-29030 | D1 DEVKIT-MPC5748G

B Monday, April 03, 2023

Index and Title Page C Neacsu Pesses Philip C Neacsu

1 15 X

# SPI_CS SPI_ESP_MOSI

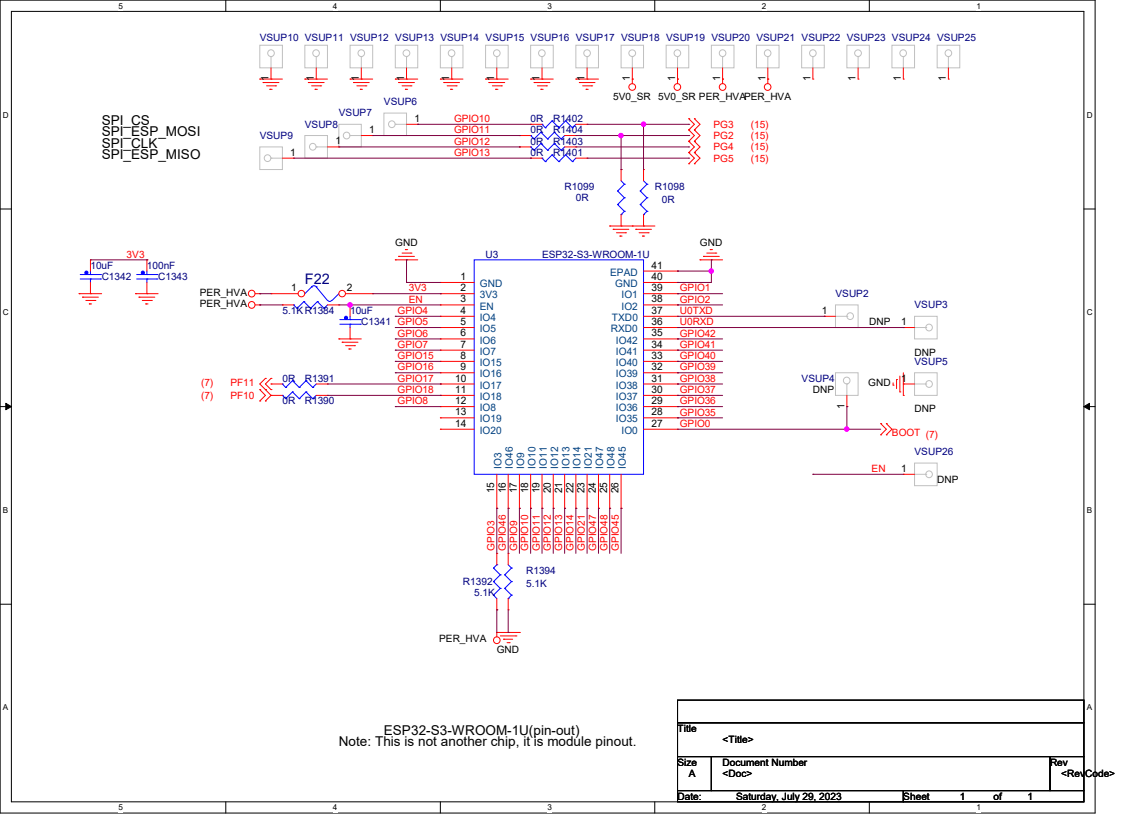
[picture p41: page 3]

ESP32-S3-WROOM-1U(pin-out)
Note: This is not another chip, it is module pinout.

# Power Input and Voltage Regulators

## Power Control

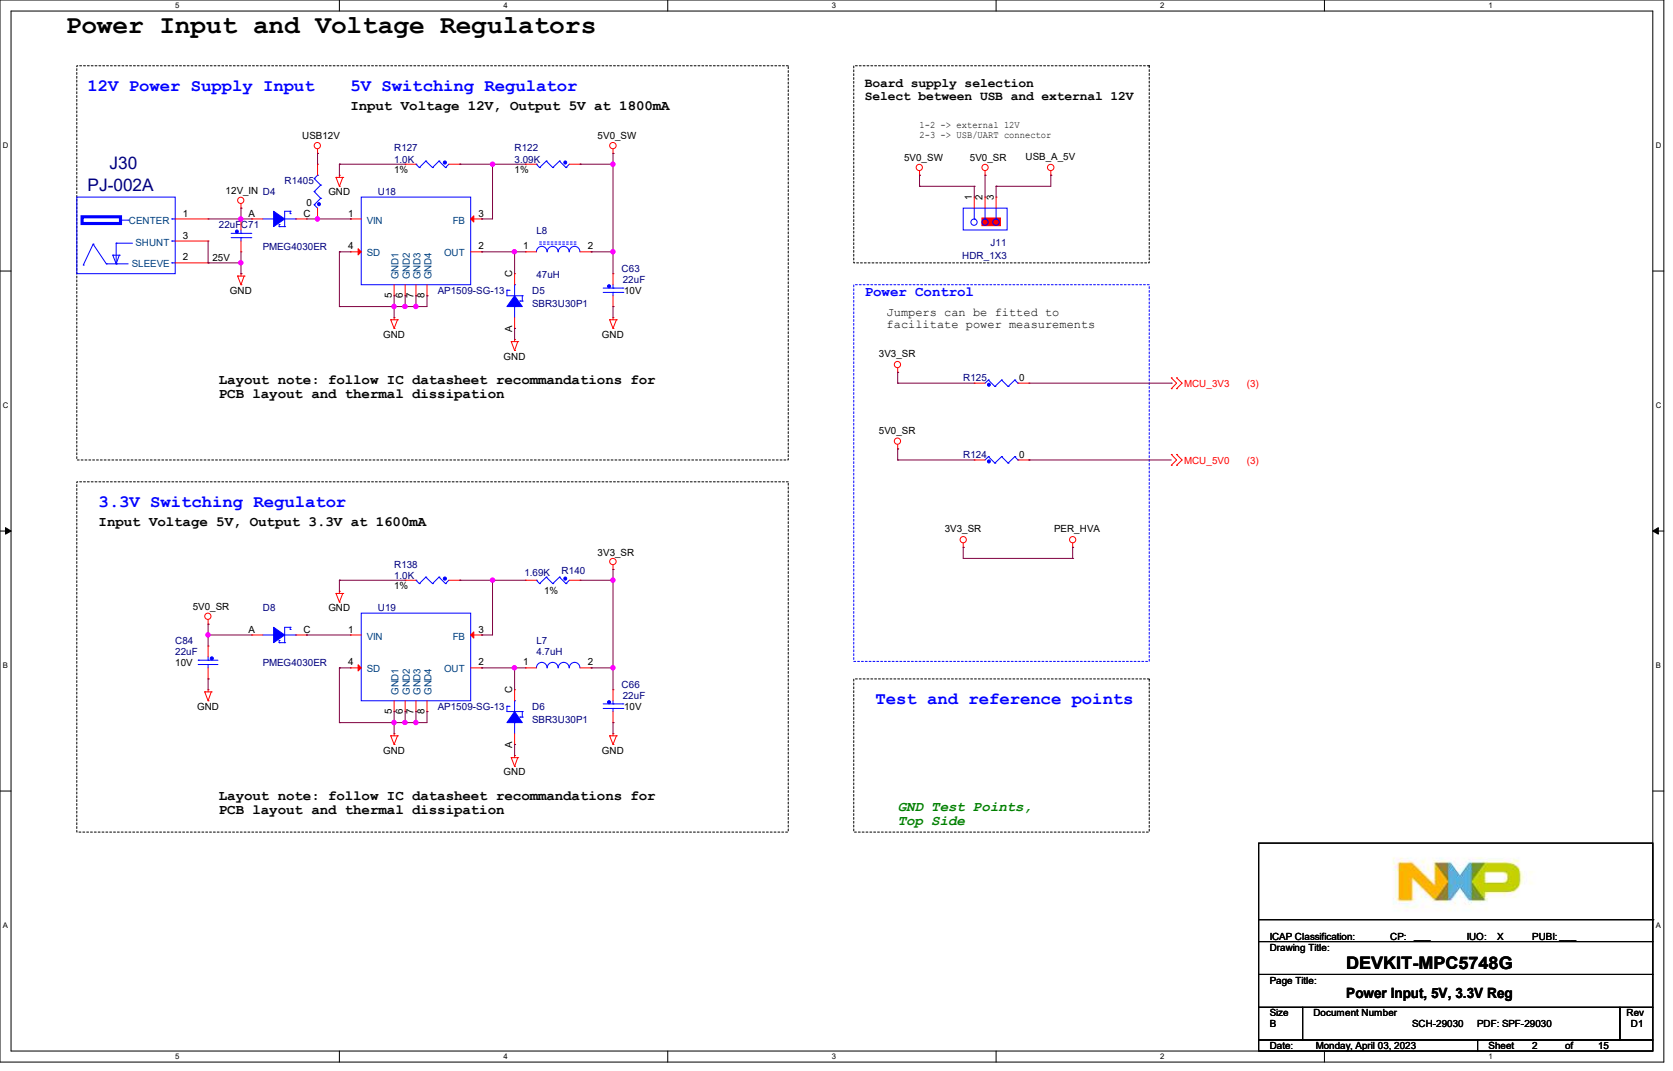
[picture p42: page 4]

Input Voltage 12V, Output 5V at 1800mA

Select between USB and external 12V 1-2 -> external 12V

Jumpers can be fitted to
facilitate power measurements

Layout note: follow IC datasheet recommandations for
PCB layout and thermal dissipation

3.3V Switching Regulator
Input Voltage 5V, Output 3.3V at 1600mA

Test and reference points

## Default Configuration:

## - ALL MCU supply voltages are set to 3.3V

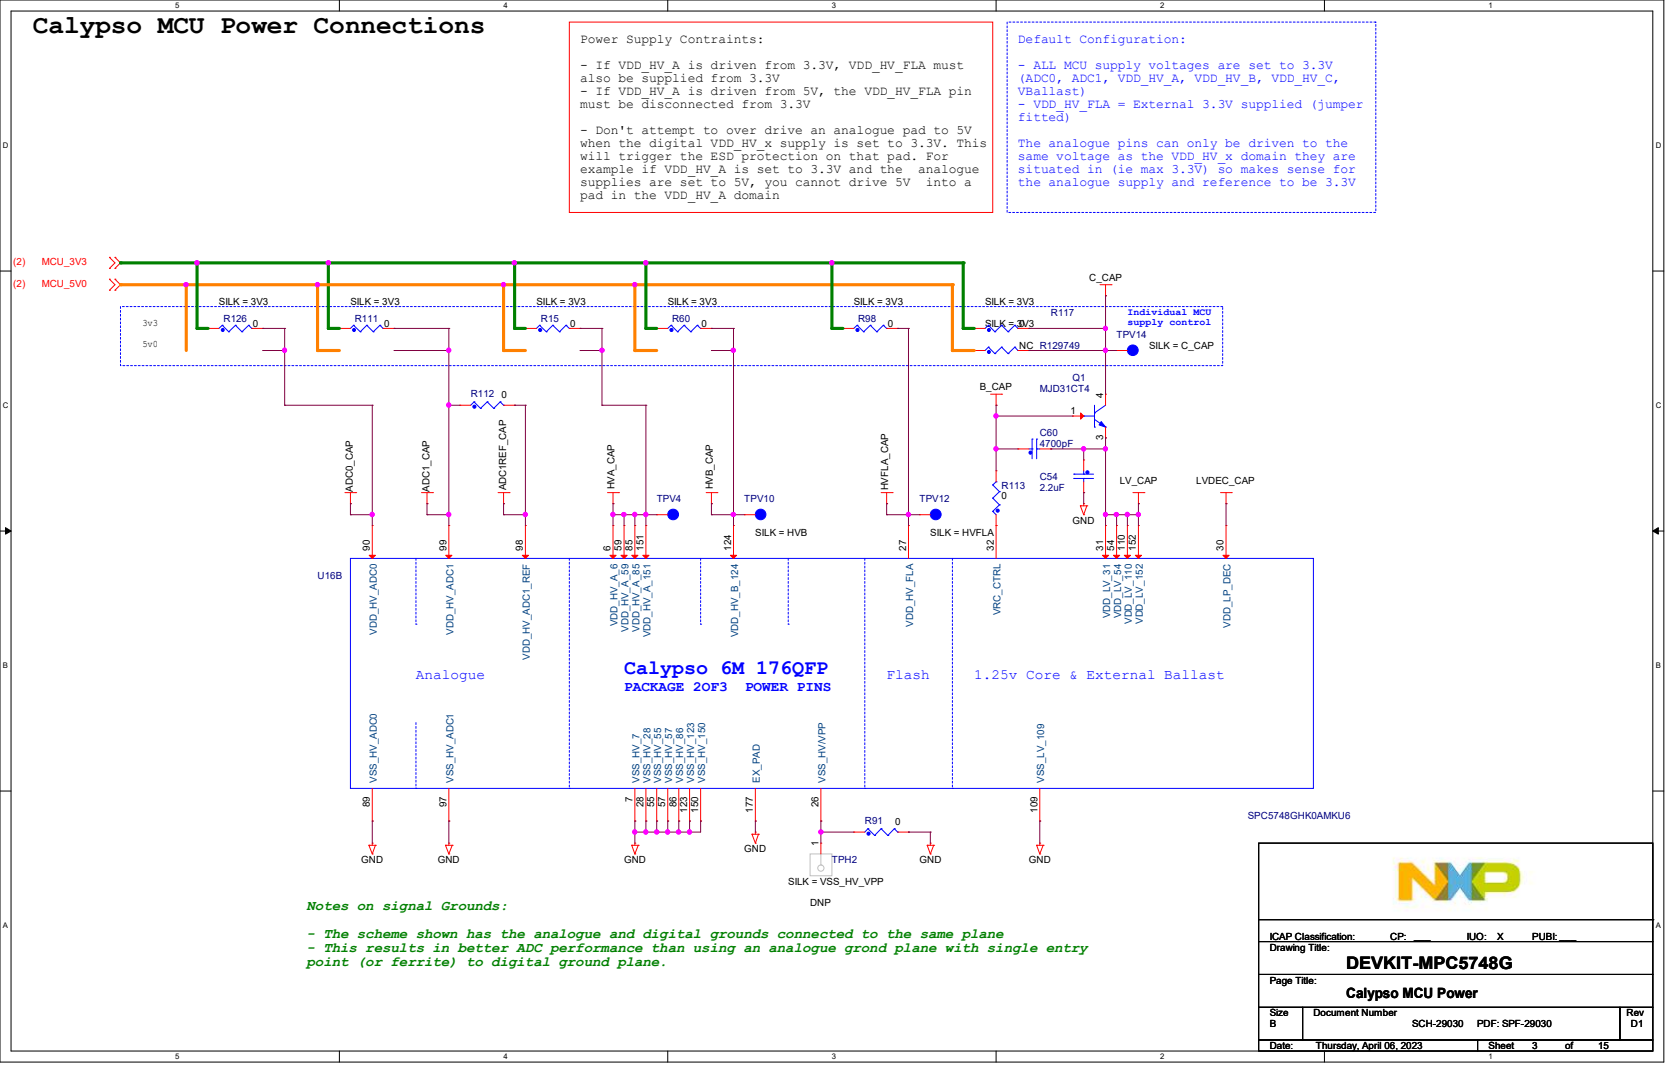
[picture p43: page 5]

- If VDD_HV_A is driven from 3.3V, VDD_HV_FLA must
also be supplied from 3.3V
- If VDD_HV_A is driven from 5V, the VDD_HV_FLA pin
must be disconnected from 3.3V
- Don't attempt to over drive an analogue pad to 5V
when the digital VDD_HV_x supply is set to 3.3V. This
will trigger the ESD protection on that pad. For
example if VDD_HV_A is set to 3.3V and the analogue
supplies are set to 5V, you cannot drive 5V into a
pad in the VDD_HV_A domain

(ADC0, ADC1, VDD_HV_A, VDD_HV_B, VDD_HV_C,
VBallast)
- VDD_HV_FLA = External 3.3V supplied (jumper
fitted)
The analogue pins can only be driven to the
same voltage as the VDD_HV_x domain they are
situated in (ie max 3.3V) so makes sense for
0 SILK = 3V3 C54

the analogue supply and reference to be 3.3V 3v3

7 VSS_HV_28 28 VSS_HV_55 55 VSS_HV_57 57 VSS_HV_86 86 VSS_HV_123 123 VSS_HV_150 150 VDD_LP_DEC 30 VSS_HV/VPP 26 EX_PAD 177 TPV12 SILK = HVFLA R60 0 SILK = 3V3 TPV10 SILK = HVB R98 0 SILK = 3V3 R112 0 TPV14 SILK = C_CAP

Notes on signal Grounds:
- The scheme shown has the analogue and digital grounds connected to the same plane
- This results in better ADC performance than using an analogue grond plane with single entry

## Place small Caps as close as possible to MCU pins
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

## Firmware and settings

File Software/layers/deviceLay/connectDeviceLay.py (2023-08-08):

# This Python file uses the following encoding: utf-8

# if __name__ == "__main__":
#     pass

from PySide6.QtNetwork import QTcpSocket,QAbstractSocket
from PySide6.QtCore import Signal, Slot
from PySide6.QtCore import QTimer

from abc import abstractmethod
import hid
import serial

from layers.threadObj_base import ThreadObj_base

from app.app_utilities import AppUtilitiesClass


"""
    物理层，线程对象类
"""

# 物理层，物理设备连接对象类
class ThreadObj_IODevice_base(ThreadObj_base):
    def __init__(self):
        super().__init__()

        self.connectDeviceParamDict = {}  # 设备连接参数字典

    # 连接设备
    @abstractmethod
    @Slot()
    def devices_open_slot(self):
        pass

    # 关闭设备
    @abstractmethod
    @Slot()
    def devices_close_slot(self):
        pass

    # 设置连接设备参数
    @abstractmethod
    @Slot()
    def devices_setConnectParam_slot(self, param):
        pass

    # 发送字节流数据
    @abstractmethod
    @Slot()
    def devices_sendByteArrays_slot(self, byteArrays):
        pass

    # 接收字节流数据，需要返回收到的字节流数据
    @abstractmethod
    @Slot()
    def devices_readByteArrays_slot(self):
        pass

    @abstractmethod
    @Slot()
    def devices_connectStatus_slot(self):
        pass


# 物理层，WIFI设备
class ThreadObj_IODevice_WIFI(ThreadObj_IODevice_base):
    def __init__(self, connectParam):
        super().__init__()

        self.connectDeviceParamDict = connectParam

    # 连接设备
    def devices_open_slot(self):
        self.socket = QTcpSocket()
        self.socket.connectToHost(self.connectDeviceParamDict["IP"], int(self.connectDeviceParamDict["PORT"]))
        return self.socket.waitForConnected(500)


    # 关闭设备
    def devices_close_slot(self):
        self.socket.close()


    # 设置连接设备参数
    def devices_setConnectParam_slot(self, param):
        self.connectDeviceParamDict["IP"] = param["IP"]
        self.connectDeviceParamDict["PORT"] = param["PORT"]

    # 发送字节流数据， 返回是否发送成功
    def devices_sendByteArrays_slot(self, byteArrays):
        bytes_written = -1
        if self.socket.isValid():
            bytes_written = self.socket.write(byteArrays)
        
        if bytes_written == -1:
            return False
        else:
            return True

    # 接收字节流数据，需要返回收到的字节流数据
    def devices_readByteArrays_slot(self):
        if self.socket.isValid():
            return self.socket.readAll()
        else:
            return None
        
    def devices_connectStatus_slot(self):
        if self.socket.state() == QAbstractSocket.ConnectedState :
            return True
        else:
            return False
        


# 物理层，USB HID设备
class ThreadObj_IODevice_USBHid(ThreadObj_IODevice_base):
    def __init__(self, connectParam):
        super().__init__()

        self.connectDeviceParamDict = connectParam
        self.dev = None

    # 连接设备
    def devices_open_slot(self):
        # self.dev = hid.device(self.connectDeviceParamDict["VID"], self.connectDeviceParamDict["PID"])
        self.dev = hid.device(vendor_id=0x0808, product_id=0x8081)
        # dev = usb.core.find(idVendor=0x0000, idProduct=0x0000)

        # self.dev = hid.
        print(self.dev)
        if self.dev is not None:
            try:
                self.dev.open()
#                manufacturer = self.dev.get_manufacturer_string()
#                product = self.dev.get_product_string()
#                serial_number = self.dev.get_serial_number_string()
            except Exception as e:
                print(e)


            # print("Manufacturer:", manufacturer)
            # print("Product:", product)
            # print("Serial Number:", serial_number)
            return True
        else:
            return False

    # 关闭设备
    def devices_close_slot(self):
        self.dev.close()

    # 设置连接设备参数
    def devices_setConnectParam_slot(self, param):
        self.connectDeviceParamDict["VID"] = param["VID"]
        self.connectDeviceParamDict["PID"] = param["PID"]

    # 发送字节流数据
    def devices_sendByteArrays_slot(self, byteArrays):
        if self.dev is not None:
            self.dev.write(byteArrays)


    # 接收字节流数据，需要返回收到的字节流数据
    def devices_readByteArrays_slot(self):
        if self.dev is not None:
            return self.dev.read(64)
        else:
            return None


# 物理层，uart 设备
class ThreadObj_IODevice_UART(ThreadObj_IODevice_base):
    def __init__(self, connectParam):
        super().__init__()

        self.serialDev = None
        self.devices_setConnectParam_slot(connectParam)

    # 连接设备
    def devices_open_slot(self):
        try:
            self.serialDev = serial.Serial(self.connectDeviceParamDict["com"], int(self.connectDeviceParamDict["baudRate"]), timeout=1)
            return True
        except serial.SerialException:
            return False


    # 关闭设备
    def devices_close_slot(self):
        if self.serialDev is None:
            return

        self.serialDev.close()

    # 设置连接设备参数
    def devices_setConnectParam_slot(self, param):
        self.connectDeviceParamDict = param

    # 发送字节流数据
    def devices_sendByteArrays_slot(self, byteArrays):
        self.serialDev.write(byteArrays)


    # 接收字节流数据，需要返回收到的字节流数据
    def devices_readByteArrays_slot(self):
        return self.serialDev.read_all()


# 物理层，设备管理类
class ThreadObj_IOManage(ThreadObj_base):

    def __init__(self, connectParam):
        super().__init__()

        self.deivceObj  = None

        # 默认连接参数字典
        self.connectParamDict = {
            "connectMode" : "WIFI",
            "USB" : {
                "VID" : "0808",
                "PID" : "8081",
            },
            "WIFI" : {
                "IP" : "192.168.0.1",
                "PORT": "3333",
            },
            "UART" : {
                "com" : "com3",
                "baudRate" : "115200",
                "dataBits" : "8",
                "parity" : "0",
                "stopBits" : "1",
            }
        }
        # 定时读取数据
        self.timerisCreated_toReadData = False


        # 定时发送心跳包
        self.timerisCreated_toSendHealthClk = False


        # 加载设备连接参数
        self.connectParamDict = AppUtilitiesClass.cfgParam_connect_load()

        # 设备的连接状态， True 表示连接成功
        self.connectStatus = False



    # 连接设备
    @Slot()
    def devices_open_slot(self):

        # 定时读取数据
        if self.timerisCreated_toReadData == False:
            self.timerisCreated_toReadData = True
            self.timer_toReadData = QTimer()
            self.timer_toReadData.setInterval(20)   # 每20ms去读取数据
            self.timer_toReadData.timeout.connect(self.devices_readByteArrays_slot)
            self.destroyed.connect(self.timer_toReadData.deleteLater)

        if self.timerisCreated_toSendHealthClk == False:
            self.timerisCreated_toSendHealthClk = True
            self.timer_toSendHealthClk = QTimer()
            self.timer_toSendHealthClk.setInterval(1000)   
            self.timer_toSendHealthClk.timeout.connect(self.devices_send_healthClk_slot)
            self.destroyed.connect(self.timer_toSendHealthClk.deleteLater)

        result = False
        self.singal_tipsPrint.emit(f"The currently selected device connection mode is:{self.connectParamDict['connectMode']}")
        self.singal_tipsPrint.emit("Device connecting...")

        if self.connectParamDict["connectMode"] == "WIFI":
            self.deivceObj = ThreadObj_IODevice_WIFI(self.connectParamDict["WIFI"])
        elif self.connectParamDict["connectMode"] == "USB":
            self.deivceObj = ThreadObj_IODevice_USBHid(self.connectParamDict["USB"])
        elif self.connectParamDict["connectMode"] == "UART":
            self.deivceObj = ThreadObj_IODevice_UART(self.connectParamDict["UART"])

        result = self.deivceObj.devices_open_slot()
        if result:
            self.connectStatus = True
            self.timer_toReadData.start()
            self.singal_tipsPrint.emit("Device connected!")

            # 发送设备配置文件给设备
            cfgParamBytes = AppUtilitiesClass.device_get_cfgParamBytes(self.connectParamDict["FRCfg"]["NODE"])
            self.devices_sendByteArrays_slot(cfgParamBytes)

            # 定时发送心跳包
            self.timer_toSendHealthClk.start()
        else :
            self.connectStatus = False
            self.timer_toReadData.stop()
            self.timer_toSendHealthClk.stop()
            self.singal_tipsPrint.emit("Device connect failed!")
            self.signal_devices_info_disconnect.emit()

        self.signal_devices_info_connectState.emit(result)


    # 关闭设备
    @Slot()
    def devices_close_slot(self):
        if self.deivceObj is None :
            self.signal_devices_info_disconnect.emit()
            return    
        
        # 定时读取数据
        if self.timerisCreated_toReadData == False:
            self.timerisCreated_toReadData = True
            self.timer_toReadData = QTimer()
            self.timer_toReadData.setInterval(20)   # 每20ms去读取数据
            self.timer_toReadData.timeout.connect(self.devices_readByteArrays_slot)
            self.destroyed.connect(lambda:(
                self.timer_toReadData.stop(),
                self.timer_toReadData.deleteLater()
            ))

        if self.timerisCreated_toSendHealthClk == False:
            self.timerisCreated_toSendHealthClk = True
            self.timer_toSendHealthClk = QTimer()
            self.timer_toSendHealthClk.setInterval(1000)   
            self.timer_toSendHealthClk.timeout.connect(self.devices_send_healthClk_slot)
            self.destroyed.connect(lambda:(
                self.timer_toSendHealthClk.stop(),
                self.timer_toSendHealthClk.deleteLater()
            ))
        self.singal_tipsPrint.emit("Connection closing....")
        self.timer_toReadData.stop()
        self.timer_toSendHealthClk.stop()
        self.deivceObj.devices_close_slot()
        self.singal_tipsPrint.emit("disconnected")
        self.signal_devices_info_disconnect.emit()
        self.deivceObj = None
        self.connectStatus = False



    # 更新设备连接参数
    @Slot(dict)
    def devices_updateConnectParam_slot(self):

        # 关闭设备
        self.devices_close_slot()
        # 更新加载参数
        self.connectParamDict = AppUtilitiesClass.cfgParam_connect_load()
        self.singal_tipsPrint.emit("Device connection parameters have been updated")

    # 发送字节流数据
    @Slot(bytes)
    def devices_sendByteArrays_slot(self, byteArrays):
        
        # print("byteArrays", byteArrays)
        if self.deivceObj is None or self.connectStatus == False:
            # 提示设备未连接, 尝试进行连接
            self.devices_open_slot()
            return
        
        status = self.deivceObj.devices_sendByteArrays_slot(byteArrays)
        if status == False:
            # 发送失败，设备连接断开
            self.devices_close_slot()

    # 接收字节流数据，需要返回收到的字节流数据
    @Slot()
    def devices_readByteArrays_slot(self):
        if self.deivceObj is None:
            return
        data = self.deivceObj.devices_readByteArrays_slot()
        if len(data) > 0:
            self.signal_devices_readData.emit(data)

    @Slot()
    def devices_connectStatus_slot(self):
        print("get result")
        result =  self.deivceObj.devices_connectStatus_slot()
        print("connect status",result)
        self.signal_devices_info_connectState.emit(result)

    @Slot()
    def devices_send_healthClk_slot(self):
        # 获取心跳包字节流
        healthClkBytes = AppUtilitiesClass.device_get_healthChkBytes()
        self.devices_sendByteArrays_slot(healthClkBytes)


    # 连接状态信号，参数表示是否成功连接
    signal_devices_info_connectState = Signal(bool)

    # 关闭设备完成信号
    signal_devices_info_disconnect = Signal()

    # 读取数据信号
    signal_devices_readData = Signal(bytes)

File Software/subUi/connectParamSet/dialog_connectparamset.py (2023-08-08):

# This Python file uses the following encoding: utf-8

# if __name__ == "__main__":
#     pass

from PySide6 import QtWidgets
from PySide6.QtCore import Signal, Slot
from PySide6.QtWidgets import QFileDialog

import serial
import serial.tools.list_ports

from subUi.connectParamSet.ui_dialog_connectparamset import Ui_Dialog_connectParamSet

from app.app_utilities import AppUtilitiesClass


class Dialog_connectParamSet(QtWidgets.QDialog):
    def __init__(self, parent=None):
        super().__init__(parent)

        self.ui = Ui_Dialog_connectParamSet();
        self.ui.setupUi(self)

        # 默认连接参数字典
        self.connectParamDict = {
            "connectMode": "WIFI",
            "USB": {
                "VID": "0808",
                "PID": "8081"
            },
            "WIFI": {
                "IP": "www.baidu.com",
                "PORT": "80"
            },
            "UART": {
                "com": "COM3",
                "baudRate": "115200",
                "dataBits": "8",
                "parity": "0",
                "stopBits": "1"
            },
            "CANCfg": {
                "SPD": "500K",
                "RES120": "ENABLE"
            },
            "FRCfg": {
                "NODE": "NodeSend"
            }
        }

        # 连接方式种类定义
        self.ui.comboBox_connectMode.insertItem(0, "UART")
        self.ui.comboBox_connectMode.insertItem(1, "WIFI")
        self.ui.comboBox_connectMode.insertItem(2, "USB")

        # fr配置选择
        self.ui.comboBox_cfgFile.insertItem(0, "NodeSend.xml")
        self.ui.comboBox_cfgFile.insertItem(1, "NodeRecv.xml")

        # can配置选择
        self.ui.comboBox_canCfg_spd.insertItem(0, "500K")
        self.ui.comboBox_canCfg_spd.insertItem(1, "250K")

        # 串口选择参数设置
        self.ui.comboBox_uartBuadRate.addItem("115200")
        self.ui.comboBox_uartBuadRate.setDisabled(True)
        self.ui.comboBox_uartCheakBits.addItem("0")
        self.ui.comboBox_uartDataBits.addItem("8")
        self.ui.comboBox_uartStopBits.addItem("1")

        # 信号连接

        # 加载参数
        self.load_connectParam(True)


    def load_connectParam(self, isFirstLoad=False):

        self.connectParamDict = AppUtilitiesClass.cfgParam_connect_load()

        # print(self.connectParamDict)

        if isFirstLoad :
            self.ui.comboBox_connectMode.blockSignals(True)
            self.ui.comboBox_connectMode.setCurrentText(self.connectParamDict["connectMode"])
            self.ui.comboBox_connectMode.blockSignals(False)
            self.ui.stackedWidget.setCurrentIndex(self.ui.comboBox_connectMode.currentIndex())
            # FR
            self.ui.comboBox_cfgFile.setCurrentText(self.connectParamDict["FRCfg"]["NODE"]+".xml")
            # CAN
            self.ui.comboBox_canCfg_spd.setCurrentText(self.connectParamDict["CANCfg"]["SPD"])
            if self.connectParamDict["CANCfg"]["RES120"] == "ENABLE":
                self.ui.checkBox_canCfg_r120.setChecked(True)
            else:
                self.ui.checkBox_canCfg_r120.setChecked(False)
            

        if self.ui.comboBox_connectMode.currentText() == "WIFI" :
            self.ui.lineEdit_IPAddr.setText(self.connectParamDict["WIFI"]["IP"])
            self.ui.lineEdit_IPPort.setText(self.connectParamDict["WIFI"]["PORT"])
            self.ui.pushButton_reflsh_com.hide()
        elif self.ui.comboBox_connectMode.currentText() == "UART" :
            self.ui.comboBox_uartPort.clear()
            self.ui.comboBox_uartPort.addItem(self.connectParamDict["UART"]["com"])
            self.ui.comboBox_uartBuadRate.setCurrentText(self.connectParamDict["UART"]["baudRate"])
            self.ui.comboBox_uartDataBits.setCurrentText(self.connectParamDict["UART"]["dataBits"])
            self.ui.comboBox_uartCheakBits.setCurrentText(self.connectParamDict["UART"]["parity"])
            self.ui.comboBox_uartStopBits.setCurrentText(self.connectParamDict["UART"]["stopBits"])
            self.ui.pushButton_reflsh_com.show()
        elif self.ui.comboBox_connectMode.currentText() == "USB" :
            self.ui.lineEdit_VID.setText(self.connectParamDict["USB"]["VID"])
            self.ui.lineEdit_PID.setText(self.connectParamDict["USB"]["PID"])
            self.ui.pushButton_reflsh_com.hide()

    @Slot(int)
    def on_comboBox_connectMode_currentIndexChanged(self, index):
        self.ui.stackedWidget.setCurrentIndex(self.ui.comboBox_connectMode.currentIndex())
        self.load_connectParam()

    @Slot()
    def on_pushButton_reflsh_com_clicked(self):

        # 遍历可用的串口名
        list_ports = list(serial.tools.list_ports.comports())
        self.ui.comboBox_uartPort.clear()
        if len(list_ports) > 0:
            for port in list_ports:
                self.ui.comboBox_uartPort.addItem(port.device)


    @Slot()
    def on_pushButton_ok_clicked(self) :
    
        # FR
        self.connectParamDict["FRCfg"]["NODE"] = self.ui.comboBox_cfgFile.currentText().split(".")[0]
        # CAN
        self.connectParamDict["CANCfg"]["SPD"] == self.ui.comboBox_canCfg_spd.currentText()
        if self.ui.checkBox_canCfg_r120.isChecked():
            self.connectParamDict["CANCfg"]["RES120"] = "ENABLE"
        else:
            self.connectParamDict["CANCfg"]["RES120"] = "DISABLE"

        self.connectParamDict["connectMode"] = self.ui.comboBox_connectMode.currentText()
        if self.connectParamDict["connectMode"] == "WIFI" :
            self.connectParamDict["WIFI"]["IP"] = self.ui.lineEdit_IPAddr.text()
            self.connectParamDict["WIFI"]["PORT"] = self.ui.lineEdit_IPPort.text()
        elif self.connectParamDict["connectMode"] == "UART" :
            self.connectParamDict["UART"]["com"] = self.ui.comboBox_uartPort.currentText()
            self.connectParamDict["UART"]["baudRate"] = self.ui.comboBox_uartBuadRate.currentText()
            self.connectParamDict["UART"]["dataBits"] = self.ui.comboBox_uartDataBits.currentText()
            self.connectParamDict["UART"]["parity"] = self.ui.comboBox_uartCheakBits.currentText()
            self.connectParamDict["UART"]["stopBits"] = self.ui.comboBox_uartStopBits.currentText()
        elif self.connectParamDict["connectMode"] == "USB" :
            self.connectParamDict["USB"]["VID"] = self.ui.lineEdit_VID.text()
            self.connectParamDict["USB"]["PID"] = self.ui.lineEdit_PID.text()

        # 保存配置参数
        AppUtilitiesClass.cfgParam_connect_save(self.connectParamDict)

        # 发送连接参数更新信号
        self.signal_CfgParam_connect_update.emit()
        # 退出对话框
        self.accept()

    @Slot()
    def on_pushButton_cancel_clicked(self):
        # 退出对话框
        self.reject()
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

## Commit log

2023-08-07 Add files via upload
    upload 3D model files
    [DB9.DXF, DB9.STL, typec.DXF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]
2023-08-07 push software
    [connectParam.cfg, sniffDataParam.cfg]
2023-08-08 update software
    [connectParam.cfg]
2023-08-16 upload hardware and firmware
    [AutoSuite-V0.3.xls, paste.csv]
